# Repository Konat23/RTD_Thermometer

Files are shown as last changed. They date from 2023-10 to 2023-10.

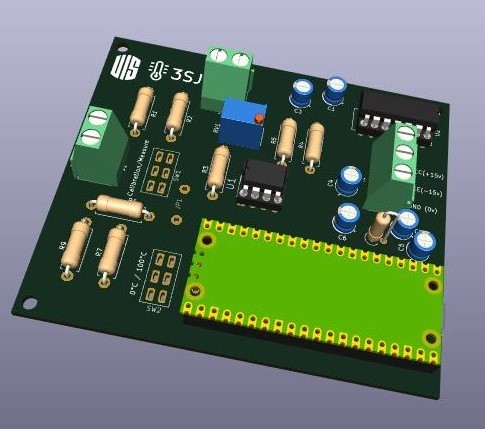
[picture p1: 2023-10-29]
pcb/docs/RTD_3D.jpg

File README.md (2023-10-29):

# RTD_Thermometer
A system that allows to measure and visualize the temperature using a thermal resistance sensor (RTD). The system was designed to measure temperatures between 0°C and 100°C with a precision of 0.1°C

## Team members
- Juan Sebastian Guerrero Peña

- Sebastian Garcia Angarita

- Juliana Lucía Pineda Cardozo 

- Laura Sofía Valero García

## Summary of Results
### Hardware design (PCB assembly)
pcb_final

### Software design (User Interface)
pyplotter

### System in operation results
Pt100_Vs_others

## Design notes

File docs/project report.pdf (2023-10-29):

# SISTEMA DE MEDICION DE TEMPERATURA ´

Guerrero Pena Juan Sebastian ˜
juan2190435@correo.uis.edu.co

García Angarita Sebastian´ sebastian2191472@correo.uis.edu.co

Valero García Laura Sofía laura2180409@correo.uis.edu.co

Pineda Cardozo Juliana Lucía juliana2185105@correo.uis.edu.co

ABSTRACT

In this project, a system that allows to measure and visualize the temperature using a thermal resistance sensor (RTD) will be implemented through different stages; linearization, filtering and digitalization, using analog and digital components in the design of these, considering the recommendations given. The project includes the design and PCB assembly of the system, as well as the visualization of the results in a graphical interface and the evaluation of the signal to noise ratio of the system.

RESUMEN

En este proyecto, se implementara un sistema que permita ´ medir y visualizar la temperatura utilizando un sensor de resistencia termica (RTD) por medio de diferentes etapas; ´
linearizacion, filtrado y digitalizaci ´ | on, utilizando componentes ´
analogicos y digitales en el dise ´ | no de estas, teniendo en cuenta ˜
las recomendaciones dadas. El proyecto incluye el diseno y ˜ ensamblaje en PCB del sistema, así como la visualizacion de ´
los resultados en una interfaz grafica y la evaluaci ´ | on de la ´
relacion se ´ | nal a ruido del sistema. ˜

### 1. INTRODUCCION´

El diseno de un sistema de medici ˜ | on de temperatura con ´
RTD es un proyecto que combina elementos analogicos y ´ digitales para obtener mediciones precisas y confiables de la temperatura utilizando un sensor de resistencia termica (RTD), ´
el cual se basa en la variacion de resistencia el ´ | ectrica en ´
funcion de la temperatura. ´
Este tipo de sensor es utilizado en una amplia gama de industrias como la automotriz, la electronica, la alimentaria ´
y la farmaceutica, debido a su alta precisi ´ | on y estabilidad, ´
ya que en estos campos se requiere un control preciso de la temperatura para garantizar la calidad y seguridad de los productos.
Por medio de este proyecto se puede verificar que a medida que la temperatura aumenta, la resistencia del RTD tambien´ se incrementa de manera predecible y lineal, permitiendo una medicion precisa de la temperatura. ´
Se busca ensamblar el diseno propuesto en este infor- ˜ me en una placa de circuito impreso (PCB) verificando su funcionamiento, al igual que al permitir la posibilidad de ser digitalizados se pueden visualizar los resultados en una
interfaz grafica lo cual facilita la interpretaci ´ | on y el an ´ | alisis ´

de los datos de temperatura, así como su monitoreo en tiempo real.

### 2. OBJETIVO GENERAL

Implementar un sistema de medicion de temperatura con ´ RTD usando elementos analogicos y digitales que permitan ´ visualizar la senal de temperatura. ˜

### 3. OBJETIVOS ESPECÍFICOS

Disenar un sistema de medici ˜ | | on de temperatura teniendo ´
en cuenta las características de la senal proporcionada ˜ por el sensor RTD usado.
Simular el sistema disenado verificando el funcionamien- ˜ to de cada etapa.
Digitalizar la senal de salida del sistema visualizando los ˜ resultados en interfaz grafica en PC. ´
Disenar y ensamblar un circuito Impreso para el sistema ˜ verificando su funcionamiento.
Determinar la relacion se ´ nal a ruido del sistema. ˜

### 4. MARCO TEORICO ´

Para este proyecto se usara como referencia el dise ´ | nõ
propuesto en [1], el cual se resumen en 5 partes; Circuito
de excitacion, circuito de linealizaci ´ | on, filtro pasa bajas, digi- ´
talizacion y cancelaci ´ | on de offset. ´

### 4.1. Circuito de excitacion´

Dado que la temperatura afecta la resistencia de la PT100, se necesita un circuito que permita la conversion de resistencia a ´
una senal el ˜ | ectrica. Para este prop ´ | osito, se emplear ´ | a el puente ´
de Wheatstone, representado en la Figura 1, que posibilita la transformacion de los valores de resistencia en valores de ´ tension. ´
La relacion entre la se ´ | nal de salida respecto a sus variables ˜
esta dada por:

Vout =

RT D
R1 + RT D

−

R3
R3 + R2
Vcc | (1)
Graficando la funcion de la Ecuaci ´ | on (1) en funci ´ | on de la ´
resistencia RT D y para distintos valores de R1 y R2, en la Figura 2 es evidente que la relacion entre la resistencia y la ´ salida no es lineal, sin embargo puede atenuarse este efecto usando valores altos de R1 y R2 y usar un rango de resistencia de la RT D que no se alejen mucho de R3. Para este proyecto se disenõ el sistema para trabajar entre 0 y 100°C, para el ´ caso de la PT100 esto equivale a una resistencia entre 100 y 138.5Ω.

Figura 1: Modelo del Puente de Wheatstone

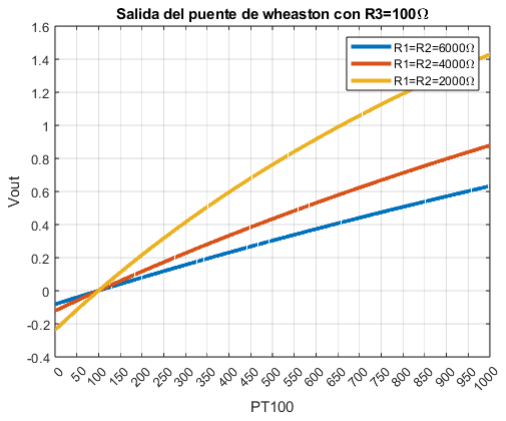
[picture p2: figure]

Figura 2: Salida del Puente de Wheatstone en funcion de la ´ resistencia Rx

### 4.2. Circuito de linealizacion´

Si bien la PT100 es uno de los sensores mas lineales que existen en el mercado, la relacion Temperatura-Resistencia ´ exhibe un comportamiento no lineal de segundo orden como se muestra en la Figura 3, de acuerdo con Bruce-Trump
[2] este problema puede ser compensado considerablemente conectando en cascada a la salida una amplificador con una
pequena retroalimentaci ˜ | on positiva como se muestra en la ´
Figura 4.
La dos parametros a ajustar en este etapa es la resistencia de ´ ganancia R8, y la resistencia de retroalimentacion positiva R5, ´
que no puede ser muy pequena por que se podr ˜ | ía desestabilizar
el circuito. El calculo de estos dos parametros son expresiones ´ largas que dependen de los rangos de salida y de entrada que se quieran medir y son facilitados en [2].

### 4.3. Circuito de filtrado de la senal ˜

Antes de la digitalizacion de la se ´ | nal es necesario hacer ˜
un filtrado a la senal para eliminar el ruido y asegurar el ˜ cumplimiento del teorema de Nyquist. Para esta etapa de filtrado, se emplea un filtro pasa bajas de segundo orden con la conocida topología Sallen-Key. Esta configuracion es ´ ampliamente utilizada en la construccion de filtros activos ´ debido a su relativa simplicidad, versatilidad y rendimiento

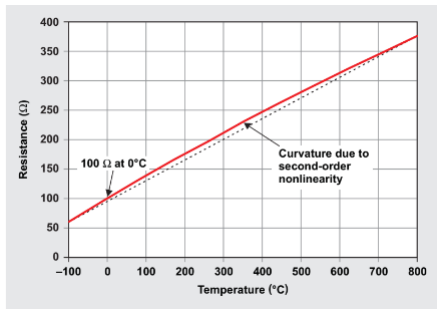
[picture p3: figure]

Figura 3: No linealidad de segundo orden. Fuente: [2]

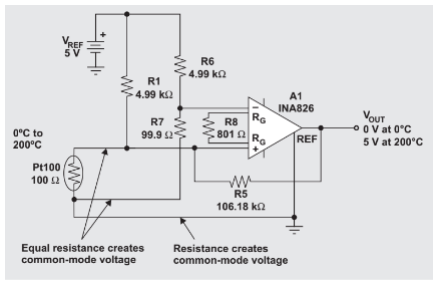
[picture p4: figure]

Figura 4: Retroalimentacion positiva para compensar no linealidad. ´ Fuente: [2]

efectivo. El circuito se configura como un filtro pasabajas o pasaalta de dos polos, donde se emplean dos resistencias, dos capacitores y un amplificador. Si se requiere un orden mayor de filtrado, es posible implementar multiples etapas en ´ cascada.
La topología Sallen-Key permite el paso de frecuencias bajas mientras atenua las frecuencias altas, lo cual es ideal para ´ el diseno de un filtro de segundo orden pasabajas, logrando ˜ así el objetivo de la etapa de filtrado en nuestro sistema de medicion de temperatura. ´

Figura 5: Topología filtro Sallen-Key de segundo orden. Fuente: [3]

En este tipo de circuito, a frecuencias altas los capacitores se comportan como corto circuitos, por lo tanto el terminal positivo del amplificador va a ir a tierra, teniendo una re-
troalimentacion positiva, la salida, tendr ´ | a la misma tensi ´ | on´

que el terminal positivo. A bajas frecuencias, los capacitores
actuaran como circuito abierto, y las dos resistencias estar ´ | an´
en serie, logrando así que a frecuencias bajas, la tension de ´ salida sea igual a la de entrada. Hay que tener en cuenta que el amplificador utilizado en este ejemplo es un buffer o de ganancia unitaria, cuando se quiere variar la ganancia se suele
poner un divisor de tension en el lazo de retroalimentaci ´ | on. ´
La respuesta en frecuencia para un circuito pasa bajas de segundo orden como el de la Figura 5 se muestra en la Figura 6 donde la pendiente de caída es de 40dB/decada.

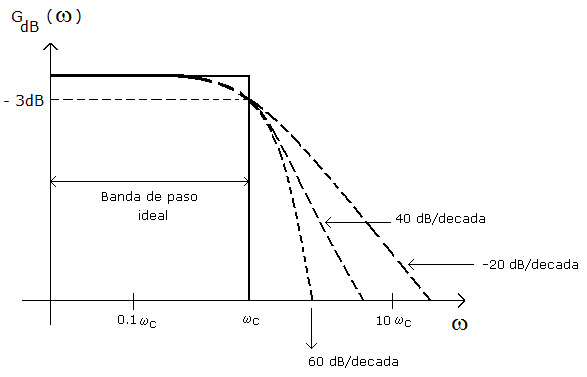
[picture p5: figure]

Figura 6: Respuesta en frecuencia filtro pasa bajas de segundo orden pasabajas. Fuente: [4]

La respuesta en frecuencia de este circuito se da por la expresion: ´
Fc =

1
2π

√
R11R12C11C12

(2)

Los pasos a seguir luego de determinar la frecuencia de corte son los siguientes:
Elegir el valor de un capacitor.
Establecer C1 = 2C2.
Elegir los valores de la resistencia.
El valor del factor de calidad y el de la constante K a la
hora de disenar el circuito, dependen de la aproximaci ˜ | on que ´
se elija.

### 4.4. Circuito de digitalizacion´

Para la digitalizacion de la temperatura medida se hace uso ´ del microcontrolador Raspberry Pi Pico. El primer microcontrolador de la familia Raspberry Pi que usa el microcontrolador RP2040 y ofrece algunas ventajas sobre la familia de microcontroladores Arduino. La placa de desarrollo es de bajo costo,
tamano reducido y bajo consumo energ ˜ | etico. ´
Segun la documentaci ´ | on t ´ | ecnica del microcontrolador [5], ´
Este integra un ADC de 12 bits de resolucion, una frecuencia ´ de muestreo de 500ksps y opera con una tension de referencia ´ interna de 3.3V.
La resolucion se refiere a la cantidad de niveles discretos ´ que el ADC puede representar en su salida digital. Con 12 bits, el ADC es capaz de generar 2

12 = 4096 niveles discretos diferentes.
El rango de voltaje de referencia utilizado en la Raspberry Pi
Pico es de 3.3V. Cuando se realiza la conversion de una se ´ | nal ˜

analogica a un valor digital, el ADC asigna uno de los 4096 ´
niveles logicos para representar el valor de la se ´ | nal anal ˜ | ogica ´
en ese instante.
Para calcular la resolucion del ADC se realiza la siguiente ´ operacion: ´

Resolucion =

3,3V
4096
= 0,00080566V | (3)
El ADC tiene la capacidad de representar una senal anal ˜ | ogi- ´
ca con una precision aproximada de 0.00080566406V por ni- ´ vel digital. Esta característica resulta sumamente util al obtener ´ mediciones precisas, especialmente cuando se digitaliza una
senal pero el rango de tensi ˜ | on es bajo. La alta resoluci ´ | on´
del ADC contribuye significativamente a obtener mediciones confiables y precisas.

### 4.5. Cancelacion de offset ´

El offset en la senal anal ˜ | ogica puede generar errores signifi- ´
cativos en las mediciones, siendo comunmente a ´ | nadido por los ˜
opamps. Para eliminar este offset, se considero inicialmente la ´
opcion de utilizar el DAC MCP47 debido a su alta resoluci ´ | on´
y facilidad de uso. Al tratarse de un DAC de 12 bits, puede
generar hasta 4096 niveles de voltaje, y su senal se usar ˜ | ía para
cancelar el offset inherente a la etapa analogica. ´
Sin embargo, debido a que el offset es una tension constante ´
y muy pequena, utilizar ˜ | unicamente el DAC para generar un ´
nivel constante puede resultar en empeorar la senal debido al ˜ reuido y la precision del DAC. ´
Por esta razon, se opt ´ | o por una cancelaci ´ | on de offset de ´
forma digital, que ofrece facilidad en su implementacion, ´ ademas de la capacidad de realizar ajustes y calibraciones ´
rapidas y confiables para eliminar peque ´ | nos errores. Esta ˜
estrategia permite corregir efectivamente las desviaciones no
deseadas en la senal anal ˜ | ogica, reducir costos y tama ´ | no del ˜
sistema, y asegurar mediciones mas precisas y consistentes. ´

### 5. METODOLOGÍA EXPERIMENTAL

5.1. Circuito de excitacion y linealizaci ´ | on´
La etapa de excitacion y linealizaci ´ | on del sistema se someti ´ | ó
a pruebas exhaustivas a traves de simulaciones y montajes en ´ el laboratorio.
El diseno se evalu ˜ | o mediante simulaciones para asegurar ´
que cumpliera con los requisitos de rendimiento y precision. ´
Posteriormente, se procedio a realizar el montaje f ´ | ísico del
circuito en el laboratorio para verificar su funcionamiento en condiciones reales.
5.1.1. Simulacion circuito de excitaci ´ | on y linealizaci ´ | on´
Las simulaciones se llevaron a cabo utilizando el software de simulacion Tina Ti [6] y el circuito dado en [2], donde se ´ tiene ya un modulo que permite simular el comportamiento de la PT100. Se ajustaron los valores de entrada y de resistencias para un rango de temperatura entre 0°C y 100°C, y de salida de 0 a 3.0V, este rango se selecciono teniendo en cuenta que el rango de entrada analogico de la Raspberry Pi Pico es de 0 ´ a 3.3V. El montaje de simulacion se muestra en la Figura 7. ´

Figura 7: Simulacion etapa de excitaci ´ | on y linealizaci ´ | on. ´

### 5.1.2. Montaje en laboratorio circuito de excitacion y ´

linealizacion´
Se conecto el INA128 de la forma que se muestra en [8] para estudiar que offset intrínseco se tenia del amplificador Operacional.

Figura 8: Montaje para medir offset INA128.

Luego, siguiendo la configuracion descrita en el apartado 4- ´
A, se realizo un montaje en el cual se reemplaz ´ | o el sensor de ´
temperatura PT100 por una resistencia de 100 Ω con tolerancia de 1 %. Se midio el voltaje a la salida. ´
Despues de eso, se incorpor ´ | o un trimmer de 200 ´ | Ω calibrado
con una resistencia de 138.5 Ω en lugar de la resistencia de 100 Ω para permitir la caracterizacion del offset de salida del ´ circuito de linealizacion´
Para caracterizar la curva de entrada salida desde el circuito de excitacion se uso la PT100 ya que es es una resistencia ´ variable, y le rango que nos interesa es de 100 Ω a 138.5 Ω, se uso como entrada un trimmer de 200 Ω, variando el valor de resistencia en la entrada en los rangos de la PT100 (100 -138.5). El montaje experimental se muestra en la Figura 9.

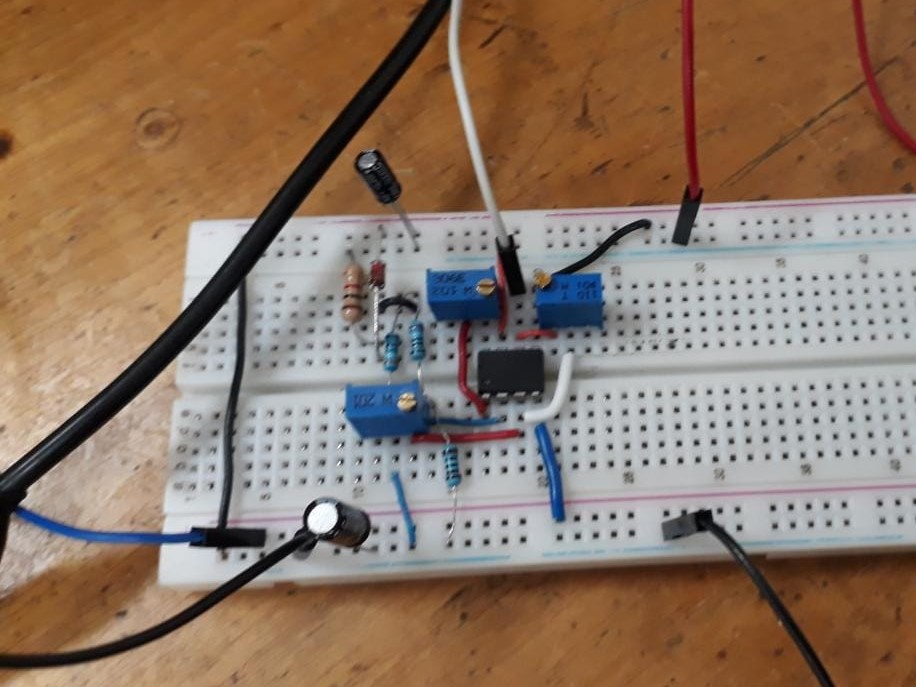
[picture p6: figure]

Figura 9: Montaje en laboratorio etapa de excitacion y linealizaci ´ | on. ´

### 5.2. Circuito de filtrado pasabajas

Usando la topología del filtro sallen-key pasabajas mencio-
nado en el marco teorico y los pasos a seguir para su dise ´ | no, ˜
se implementa un filtro, teniendo en cuenta que tanto varia la temperatura.

### 5.2.1. Diseno del circuito de filtrado pasabajas ˜

La frecuencia de corte utilizada para el diseno de este filtro ˜ debía cumplir con la característica de ser una frecuencia baja con el objetivo de permitir el paso de las frecuencias mas bajas ´ y atenuar las frecuencias altas, por esto mismo, se eligio un ´
valor de 10Hz, aquí se tendra una atenuaci ´ | on de -3dB. ´
En el diseno, al utilizar una aproximaci ˜ | on Butterworth, se ´
esta definiendo un factor de calidad de 0.707, se elige esta ´ aproximacion ya que se quiere obtener una respuesta plana ´ en la banda pasante, esto se refleja en un voltaje de salida constante hasta la frecuencia de corte. Para el calculo de los demas elementos del sistema se tiene en cuenta que el ´ amplificador va a actuar como un buffer, por lo tanto su ganancia va a ser igual a 1.
Calculo del valor de los capacitores: ´
C1 = 10µF => C2 = 2(10µF) | (4)

Calculo del valor de las resistencias: ´

R1 = R2 | (5)

Verificacion en la formula de frecuencia de corte: ´

Fc =

1
2π

p
(1,13kΩ)(1,13kΩ)(10µF)(20µF)

(6)

En resumen, los datos utilizados para la construccion del ´ filtro fueron los siguientes:

Parametro ´ | Valor
Capacitor 1 | 10µF
Capacitor 2 | 20µF
Resistencia 1 | 1,13kΩ
Resistencia 2 | 1,13kΩ
Frecuencia de corte | 10Hz
Q | 0.707
Tabla 1: Descripcion de par ´ | ametros ´
De esta etapa se implemento una simulaci ´ | on y se caracteriz ´ | ó
el circuito en laboratorio.

### 5.2.2. Simulacion circuito de filtrado pasabajas ´

Al circuito que ya se tenia montado en el software de
simulacion Tina Ti, se le agreg ´ | o la etapa de filtrado que se ´
muestra en la Figura 10. Conectando a la entrada senales ˜ de distintas frecuencias y midiendo su salida para hallar la respuesta en frecuencia.

### 5.2.3. Montaje en laboratorio del circuito de filtrado

pasabajas
Se realizo el montaje del filtro pasabajas por independiente ´ para poder estudiar la respuesta en frecuencia haciendo un barrido de frecuencias. El montaje se muestra en la Figura 11.

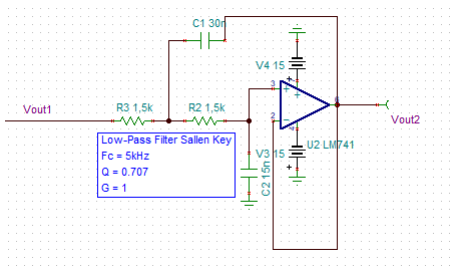
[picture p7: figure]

Figura 10: Simulacion etapa filtrado. ´

Figura 11: Montaje en laboratorio de etapa filtrado.

### 5.3. Caracterizacion PT100 ´

La caracterizacion de la PT100 [7],es una etapa esencial ´ en el desarrollo. Esta fase se lleva a cabo para comprender el comportamiento y la respuesta real de la PT100 ante diferentes condiciones de temperatura, lo que permite calibrar adecuadamente el sistema.
La PT100 es el tipo de RTD mas utilizado en aplicaciones ´ industriales y de medicion de temperatura. Su nombre deriva ´ del estandar que indica que a 0°C debe tener una resistencia ´ de 100Ω. No obstante, cada PT100 puede presentar pequenas ˜ desviaciones o no ser totalmente lineal en su respuesta. Por lo tanto, es esencial caracterizarla y compararla con el estandar ´ de referencia, como se muestra en la Tabla 6.5 en [8], para determinar su comportamiento real y aplicar correcciones a las medidas obtenidas.
Con el fin de realizar la caracterizacion, se llevaron a cabo ´ mediciones utilizando agua a diversas temperaturas, dentro del
rango de 0°C a 100°CPara este prop ˙ | osito, se utilizaron dos ´
sensores de temperatura patron: una termocupla del mult ´ | ímetro
digital UNI-T UT33C+ [9] y un termometro de alimentos ´ TP300 [10].
Los dos sensores, junto con la pt100, fueron cuidadosamente ubicados en un mismo punto y a la misma altura, garantizando mediciones precisas y coherentes entre los dispositivos. Este enfoque nos brindo datos confiables y detallados, esenciales ´ para llevar a cabo la caracterizacion requerida de manera ´ efectiva.

Figura 12: Termocupla del multímetro digital UNI-T UT33C+

Figura 13: Termometro Digital TP300 ´

Figura 14: Montaje en laboratorio de etapa de caracterizacion PT100 ´

### 5.4. Digitalizacion´

En el proceso de digitalizacion, se siguieron algunas reco- ´ mendaciones proporcionadas en el datasheet de la Raspberry Pi Pico sobre el uso del ADC [5, p. 17-19]. Estas recomendaciones incluyen desactivar el modo de ahorro de energía para eliminar el rizado en la alimentacion y garantizar una mayor ´ estabilidad durante las mediciones.
Ademas, se a ´ | nadi ˜ | o una resistencia entre los pines ´
ADC VREF y 3V3 (ver Anexo 1) para reducir el offset en la senal. Sin embargo, es importante mencionar que esta ˜ reduccion del offset incrementa el ruido del ADC. Para contra- ´ rrestar tanto el ruido como el offset, se promediaron multiples ´ muestras y uso un segundo canal del ADC conectado a GND ´ y se considero esta medida como el offset propio del ADC. ´ Sin embargo, durante las pruebas en laboratorio, se observó que la cancelacion de offset empeoraba las mediciones y, ´ contrariamente, introducía un offset negativo en las medidas.
Por esta razon se opt ´ | o por no hacer esta cancelaci ´ | on de ´
offset y mejorar las mediciones usando una calibracion con ´ las resistencias de referencia.

### 5.5. Sistema de auto calibracion´

Para la correccion del offset de las etapas anal ´ | ogicas y ´
el offset del ADC, así como para garantizar un correcto funcionamiento del sistema y mitigar posibles efectos de constantes externas o desajuste en la ganancia, se implementó un sistema de auto calibracion. Este sistema utiliza resistencias ´ de referencia que posibilitan el ajuste preciso de la etapa de digitalizacion. ´

Figura 15: Sistema de auto calibracion´

A traves de un arreglo de switches, Figura 15, es posible ´ alternar entre las resistencias de referencia, lo que permite al microcontrolador ajustar dos puntos de calibracion clave. ´ Gracias a este enfoque, no es necesario calcular o medir el offset en la etapa analogica ni en el ADC. En su lugar, el ´ microcontrolador puede trazar una recta entre esos puntos de
calibracion, calcular su ecuaci ´ | on y, debido a la linealidad del ´
sistema, obtener mediciones precisas y confiables de cualquier resistencia, y por ende, la temperatura de la PT100.

### 5.6. Interfaz de visualizacion´

Para la visualizacion de la temperatura, se desarroll ´ | o una ´
interfaz grafica en Python llamada PyPlotter [11]. Esta interfaz ´ permite establecer conexion con cualquier microcontrolador ´ mediante el protocolo UART y visualizar graficamente los ´ valores enviados por el microcontrolador.

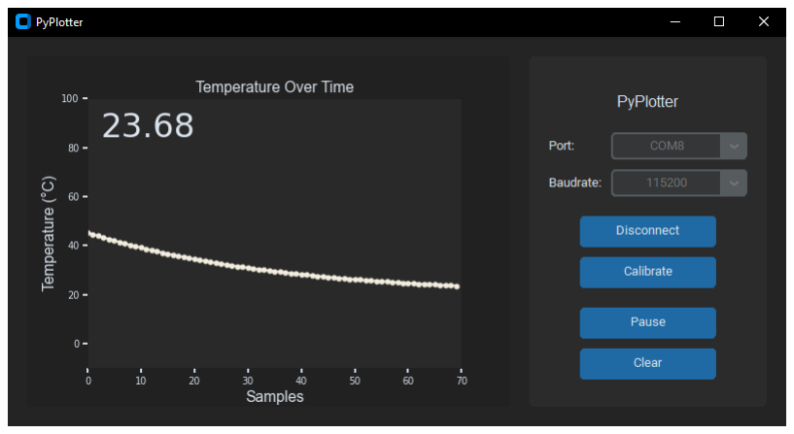
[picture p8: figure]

Figura 16: Interfaz grafica PyPlotter ´

Es importante destacar que la programacion en MicroPython ´ o CircuitPython, utilizadas en la Raspberry Pi Pico, no permite una comunicacion directa mediante el protocolo UART a ´ traves de USB. En su lugar, se emplea el REPL (Read-Eval- ´ Print Loop) que funciona como una terminal interactiva en el microcontrolador, permitiendo enviar comandos y recibir respuestas.
Debido a esta limitacion, la Raspberry Pi Pico fue progra- ´ mada utilizando el IDE de Arduino en lenguaje C++, lo que
permitio establecer la comunicaci ´ | on mediante UART y enviar ´
los datos necesarios para su visualizacion en la interfaz gr ´ | afica ´
PyPlotter.
Ademas, la interfaz proporciona la opci ´ | on de realizar la ´
calibracion del sistema. Esto permite calibrar inicialmente ´ utilizando una resistencia de referencia y luego cambiar a otra resistencia para completar la calibracion de manera efectiva. ´ Aunque PyPlotter se creo originalmente para este proyecto ´ en particular, ha experimentado una evolucion significativa ´ y se ha convertido en un proyecto paralelo utilizado en
otras asignaturas. Su facil personalizaci ´ | on y funcionalidad han ´
sido favorables en distintos contextos, proporcionando una herramienta valiosa para la visualizacion de datos provenientes ´ de microcontroladores.

### 5.7. Diseno de PCB ˜

Luego de verificar el funcionamiento del circuito en el
laboratorio, se procedio al dise ´ | no y montaje de la impresi ˜ | on´
del circuito en una PCB. El montaje incorporo el sistema de ´
switches mencionado en la Seccion de Auto Calibraci ´ | on (ver ´
Seccion´ 5.5).

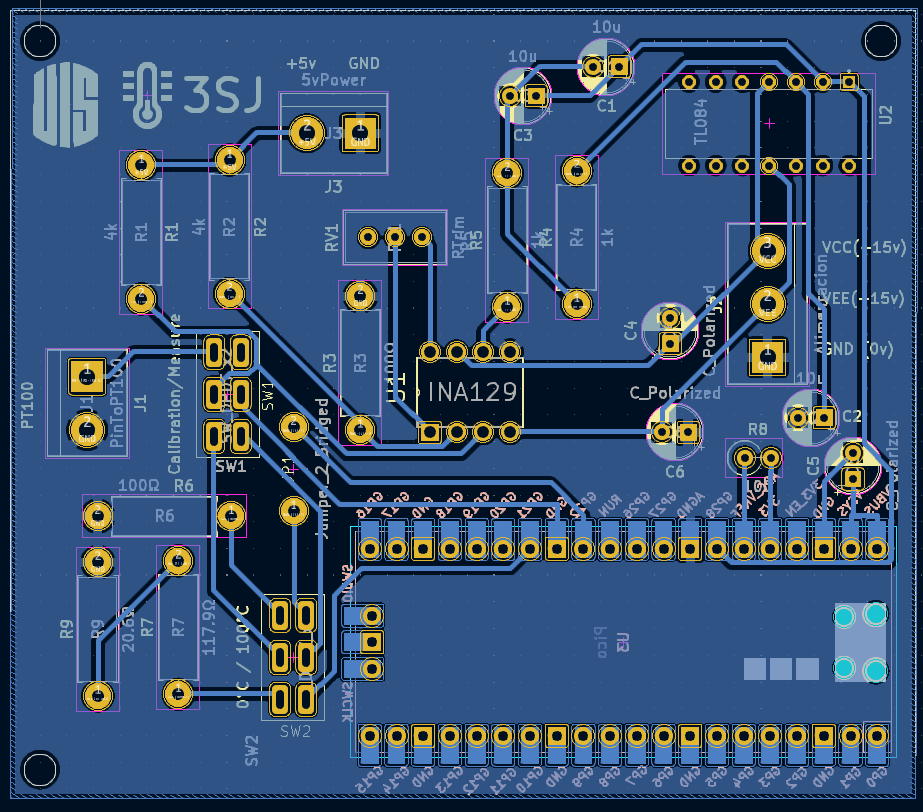
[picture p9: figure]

Figura 17: Diseno de PCB. ˜

El diseno de la PCB se presenta en la Figura 17, mientras ˜ que el esquema de conexiones se muestra en el Anexo 1. El layout de la PCB se proporciona a escala real en el Anexo
2. Asimismo, para una mejor visualizacion y comprensi ´ | on del ´
diseno, el modelo 3D de la PCB se puede ver en la Figura 18. ˜

### 6. ANALISIS DE RESULTADOS ´

6.1. Circuito de excitacion y linealizaci ´ | on´
Se realizo una medici ´ | on experimental del voltaje de offset ´
generado por el amplificador de instrumentacion INA128 ´ utilizando un osciloscopio.


Figura 18: Diseno de PCB visualizado en 3D. ˜

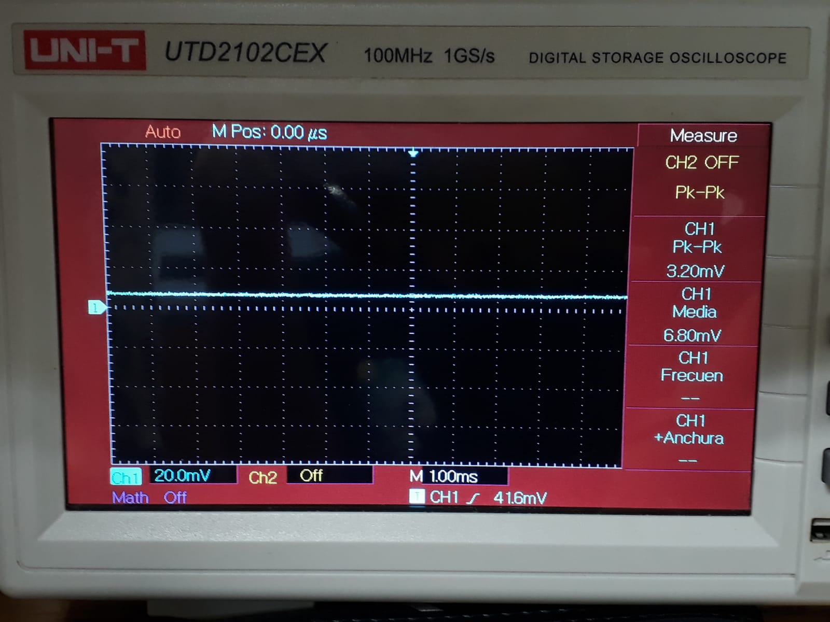
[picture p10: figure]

Figura 19: Offset del amplificador de instrumentacion INA128 ´

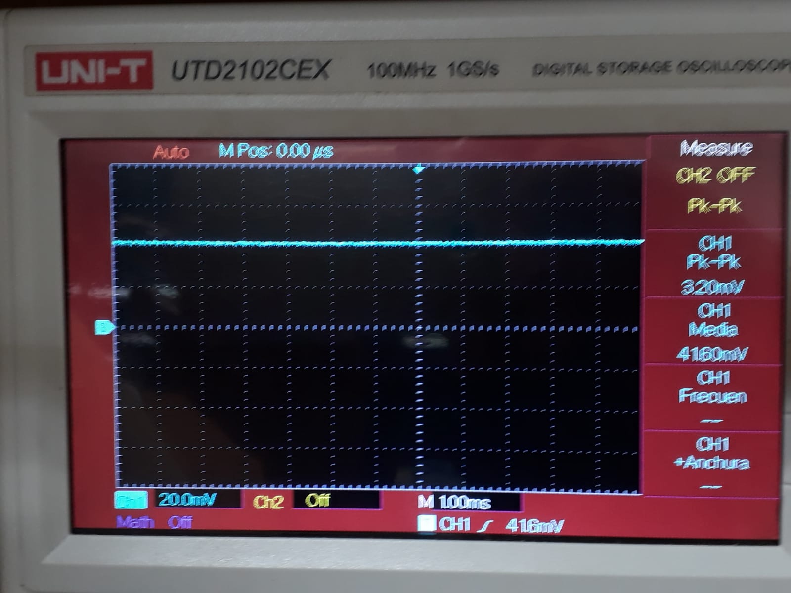
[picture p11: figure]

Figura 20: Offset en 0

◦C

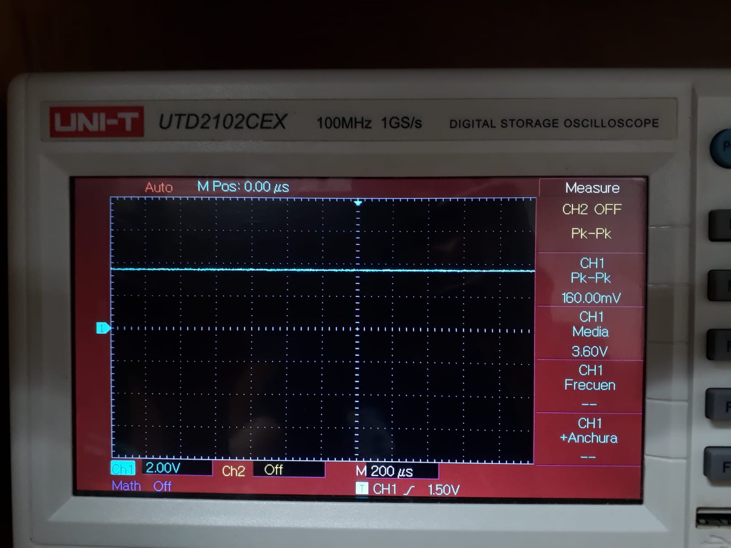
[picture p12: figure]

Figura 21: Offset en 100◦C

6.1.1. Resultados simulacion Circuito de excitaci ´ | on y ´
linealizacion´
Haciendo el barrido en la entrada de 0°C a 100°C, se obtuvo la grafica que se muestra en la Figura 22. ´

Figura 22: Resultado de simulacion barrido de temperatura etapa de ´ linealizacion´

Para el circuito de linealizacion, se realizaron pruebas de ´ comparacion para determinar la necesidad de utilizar feedback ´ positivo dentro del rango de valores de trabajo, que abarcaba desde 0 °C hasta 100 °C. Para ello, se comparo el com- ´ portamiento del circuito con y sin feedback positivo, y los resultados se presentan en la figura 23.
Al analizar los resultados de la comparacion de mediciones ´ y el error, se observo que sin el feedback positivo se obtuvo ´ una menor cantidad de error. Esto se debe a que, teoricamente, ´ como se muestra en la grafica 25, la PT100 dentro de este ´ rango de valores exhibe un comportamiento lineal. Por lo tanto, prescindir del feedback positivo permitio una mayor ´ aproximacion a los valores ideales de la PT100. ´

### 6.2. Circuito de filtrado pasabajas

### 6.2.1. Simulacion circuito de filtrado pasabajas ´

Se hace un barrido en frecuencia para ver como responde el circuito mostrado en la Figura 10, obteniendo la grafica ´ mostrada en la Figura 26.
En la Figura 26, se puede observar el resultado de la simula-
cion del barrido en frecuencia para el filtro pasabajas dise ´ | nado. ˜

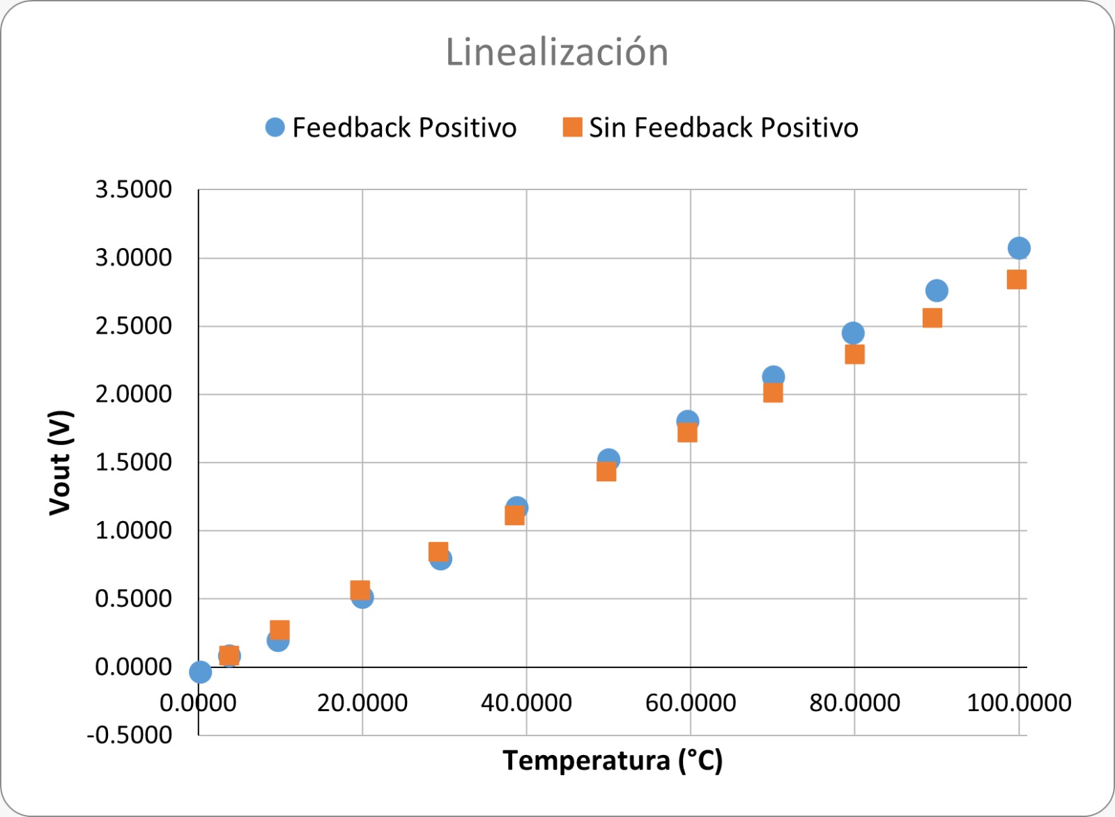
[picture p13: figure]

Figura 23: Comparacion de mediciones con feedback positivo y sin ´ feedback

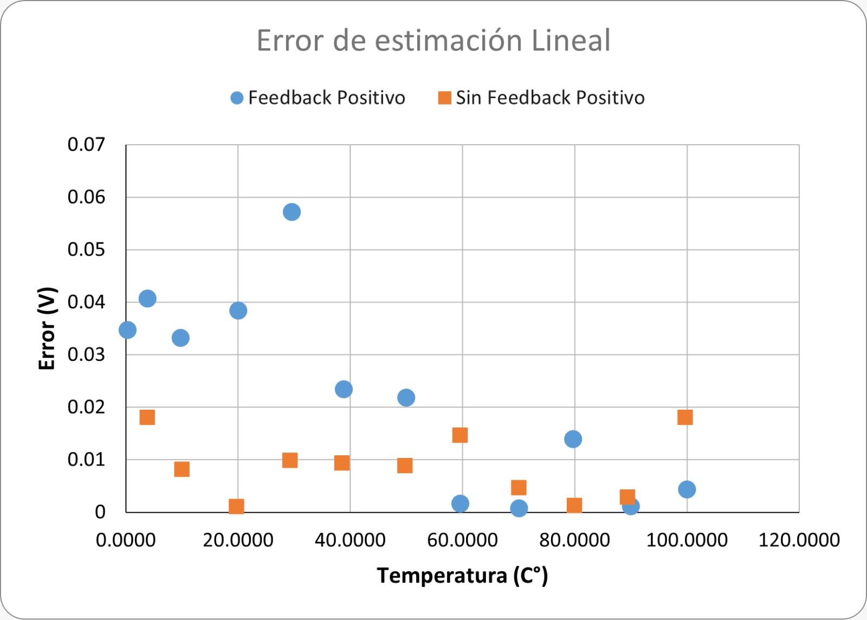
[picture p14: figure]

Figura 24: Error de estimacion lineal ´

Figura 25: Grafica del comportamiento del sensor de temperatura ´ PT-100. Fuente: [12]

Figura 26: Resultado de simulacion barrido en frecuencia para filtro ´ pasabajas

Observamos que la caída de -3dB ocurre en la frecuencia objetivo de 10Hz,con la cual fue disenado el circuito. ˜ Luego, para obtener una validacion experimental del com- ´ portamiento del filtro pasabajas, se realizaron mediciones utilizando dos amplificadores operacionales diferentes. La Figura 27 muestra el resultado experimental del barrido en frecuencia utilizando el amplificador operacional LM741, mientras que la Figura 28 presenta los resultados utilizando el amplificador operacional TL084.

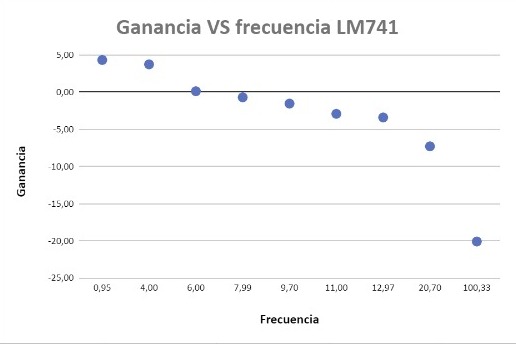
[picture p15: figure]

Figura 27: Resultado experimental de barrido en frecuencia para filtro pasabajas con amplificador LM741

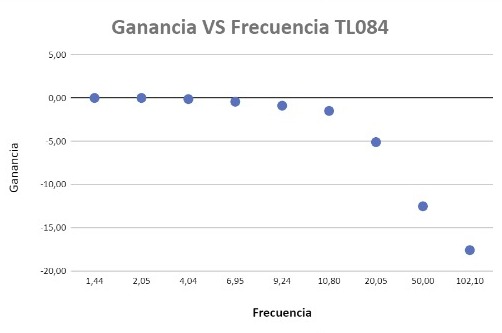
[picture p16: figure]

Figura 28: Resultado experimental de barrido en frecuencia para filtro pasabajas con TL084

En el caso del amplificador operacional LM741, se observa que la caída de -3dB ocurre nuevamente cerca de la frecuencia objetivo de 10Hz. Sin embargo, a medida que aumenta la frecuencia, la atenuacion no se mantiene constante y presenta ´ ciertas fluctuaciones en el comportamiento del filtro. Esto puede deberse a limitaciones del amplificador en altas frecuencias o a efectos de ruido y distorsion que influyen en la respuesta ´ del filtro. Por otro lado, al utilizar el amplificador operacional TL084, se observa un comportamiento mas cercano al de ´ un filtro con una característica tipo Butterworth. La curva
de atenuacion muestra una forma m ´ | as suave y consistente ´
a lo largo del rango de frecuencias medidas. Esto sugiere que el TL084 es mas adecuado para funcionar como un filtro ´

pasabajas con un comportamiento mas predecible y estable en ´ un rango mas amplio de frecuencias. ´

### 6.3. Analisis de ruido ´

En el analisis de ruido del sistema, se llevaron a cabo ´
calculos te ´ | oricos y simulaciones espec ´ | íficas para evaluar el
nivel de ruido presente en el sistema completo, centrandonos ´ principalmente en el ruido de los amplificadores. Los calcu- ´ los teoricos arrojaron un valor estimado de ruido total de ´ aproximadamente 2.3584 µV (Ver anexo 3), mientras que las simulaciones mostraron un valor ligeramente mayor, alrededor de 2.37 µV .

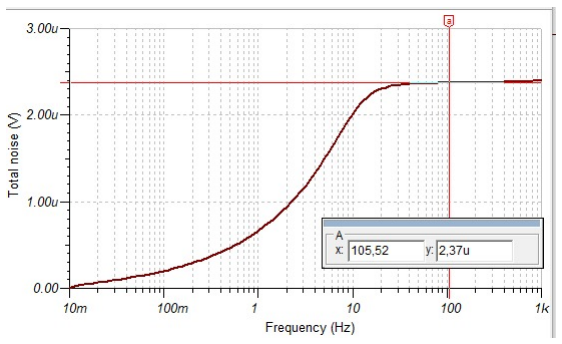
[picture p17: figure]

Figura 29: Resultado analisis del ruido total ´

La Figura 29 presenta los resultados del analisis del ruido ´ total.
Ademas, se realiz ´ | o un an ´ | alisis de la Relaci ´ | on Se ´ | nal-Ruido ˜
(SNR) para evaluar la calidad de la senal de inter ˜ | es en relaci ´ | on´
con el ruido presente en el sistema. La Figura 30 muestra los resultados del analisis SNR, donde se visualiza claramente la ´ relacion entre la frecuencia y la SNR expresada en decibelios ´
(dB).De manera teorica se llego a un ´ | SNR = 65,816dB (Ver
anexo 3) para el ancho de banda de 10Hz, sin embargo no es posible compararlos con los resultados de simulacion ya que Tina-Ti no permite ver el SNR en un ancho de banda definido.

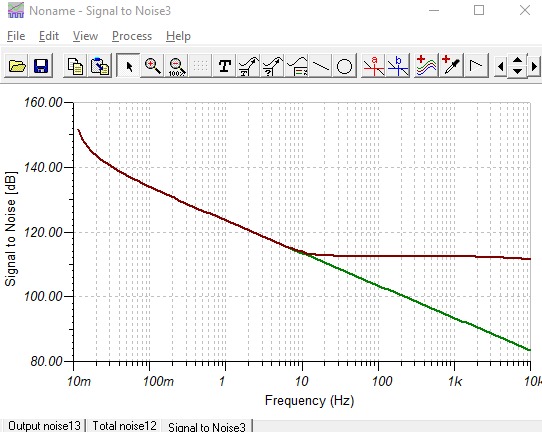
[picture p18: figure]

Figura 30: Resultado analisis SNR ´

Todos calculos te ´ | oricos detallados se encuentran disponibles ´
en el anexo 3 del informe para una referencia detallada. Los
anexos proporcionan una vision completa de la metodolog ´ | ía
utilizada en los calculos te ´ | oricos y permiten una mayor com- ´
prension del an ´ | alisis tanto del ruido como del SNR del sistema. ´

### 6.4. Caracterizacion PT100 ´

Se recolectaron los datos de los dos sensores patron y la ´ PT100, tal como se muestra en la Tabla 2. Luego de obtener
estos datos, se procedio a crear una gr ´ | afica comparativa entre ´
los valores medidos como se ilustra en la figura 31.
PT100 Ω | TP300 °C | Termocupla °C
133.7 | 79.3 | 81
130.9 | 74.3 | 72
129.9 | 66.6 | 70
129.1 | 66.5 | 68
127.6 | 63.6 | 64
126.4 | 60.6 | 60
124.8 | 56.3 | 56
122.2 | 50.1 | 49
120.8 | 46.2 | 45
119.3 | 42.5 | 42
117.3 | 37.5 | 37
115.8 | 33.2 | 32
112.9 | 25.4 | 24
110.4 | 20.6 | 17
109.2 | 13.8 | 14
104.7 | 2.1 | 0

Tabla 2: Mediciones de PT100, TP300 y termocupla

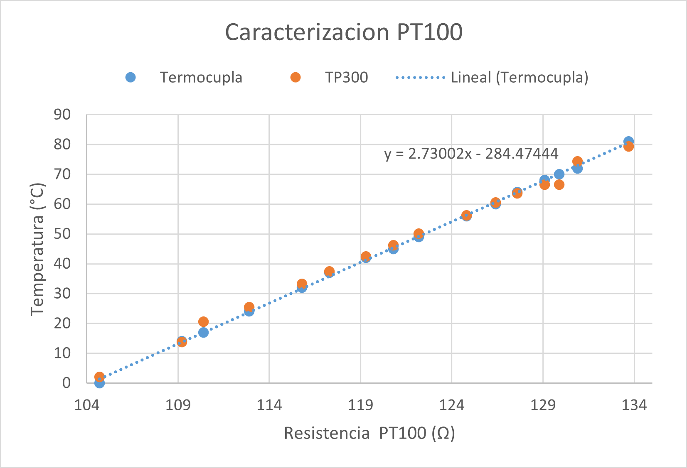
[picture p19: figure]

Figura 31: Curva de caracterizacion PT100 ´

Tras analizar los resultados obtenidos en la Figura 31, se puede concluir que la termocupla presenta un comportamiento
mas lineal en comparaci ´ | on con el sensor TP300. Este aspecto ´
ha sido determinante en la eleccion del sensor patr ´ | on para el ´
proceso de caracterizacion. ´
La termocupla demostro una mayor proximidad y ajuste a ´ la línea recta que representa la variacion de la PT100 respecto ´ a la temperatura. Esta mayor linealidad en el comportamiento de la termocupla sugiere una respuesta mas precisa y confiable ´ a los cambios de temperatura. Como resultado, al utilizar la interfaz para visualizar la temperatura de la PT100, obtuvimos resultados mucho mas cercanos a los proporcionados por la ´ termocupla.

### 6.5. Digitalizacion´

Las pruebas realizadas para la cancelacion del offset propio ´ del ADC demostraron que, contrariamente a lo que se pensaba y recomendaba en el datasheet [5, p. 17], la cancelacion del ´ offset empeoraba las mediciones de voltaje en el ADC. Esto se puede apreciar claramente en la Figura 32, donde se observa
que al medir la maxima tensi ´ | on despu ´ | es de la cancelaci ´ | on del ´
offset, los resultados son peores en comparacion con la lectura ´ directa del ADC.

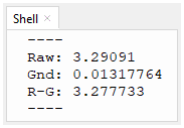
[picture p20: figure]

Figura 32: Resultados de cancelacion offset del ADC ´

Se llevaron a cabo diversas pruebas utilizando distintos voltajes, pero los mejores resultados, comparando con un multímetro y osciloscopio, se obtuvieron al realizar la lectura directa del ADC, sin aplicar la cancelacion de offset. ´
La resolucion del ADC y, por ende, la resoluci ´ | on efectiva ´
en la medicion de la temperatura se ven afectadas por las ´ modificaciones realizadas de acuerdo a las recomendaciones en el datasheet, ver Seccion´ 5.4. Sin embargo, es importante tener en cuenta que el numero efectivo de bits (ENOB) del ´ ADC no es realmente 12 bits, como se menciona en el datasheet de la placa de desarrollo de la Raspberry Pi Pico [5].
En la documentacion del microcontrolador RP2040 [13, ´ sec 4.9.3], se especifica que el ENOB típico es de 8.7 bits. Considerando los ajustes realizados en nuestro sistema y que
la caracterizacion en la documentaci ´ | on se llev ´ | o a cabo con ´
equipos de alta calidad y bajo nivel de ruido, el ENOB de nuestro sistema se estima en aproximadamente 7.96 bits. Este valor se calculo teniendo en cuenta el voltaje registrado con ´ el ADC conectado a GND.

### 6.6. Resultados diseno de la PCB ˜

Una vez impresa la PCB, se procedio al montaje y soldadura ´ de los componentes. Durante esta fase, se llevo a cabo una ´ cuidadosa medicion de las resistencias empleadas, utilizando ´
equipos de medicion de alta precisi ´ | on, con el objetivo de ´
conocer los valores reales del sistema. Esto permitio realizar ´ una calibracion precisa del sistema y ajustar adecuadamente ´ los puntos de referencia del puente de Wheatstone, necesarios para una medicion exacta de la temperatura. ´
En la Tabla 3 se presentan las mediciones de las resistencias utilizadas en la PCB, junto con sus indicativos correspondientes en el esquematico que se encuentra en el Anexo 1. ´

### 6.7. Resultado final

Despues del montaje en PCB del sistema se hicieron pruebas ´ finales del comportamiento y precision del sistema usando la ´

Resistencia | Valor Ω
R1 | 3880
R2 | 3880
R3 | 99.9
R6 | 100.7
R7 | 117.5
R9 | 20.2

Tabla 3: Valor real de resistencias usadas

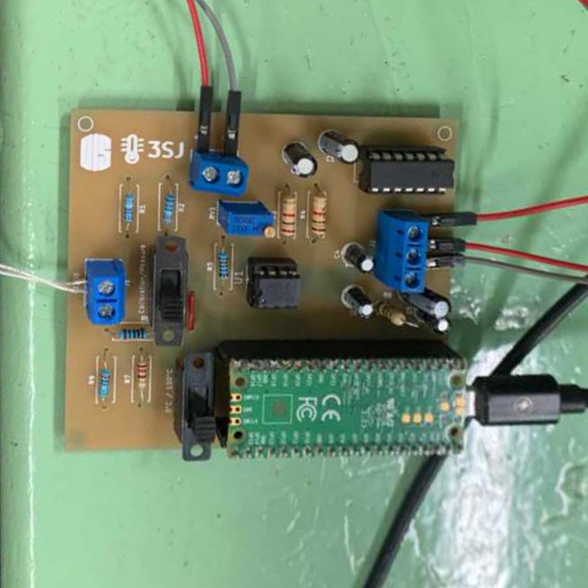
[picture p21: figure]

Figura 33: Resultado final en la PCB

interfaz grafica. En la Figura 34 se muestra un gr ´ | afico com- ´
parativo de temperatura vs. temperatura, donde se comparan las mediciones de la PT100 en la interfaz implementada, con las mediciones realizadas utilizando dos termometros patrones: ´ una termocupla y un TP300.

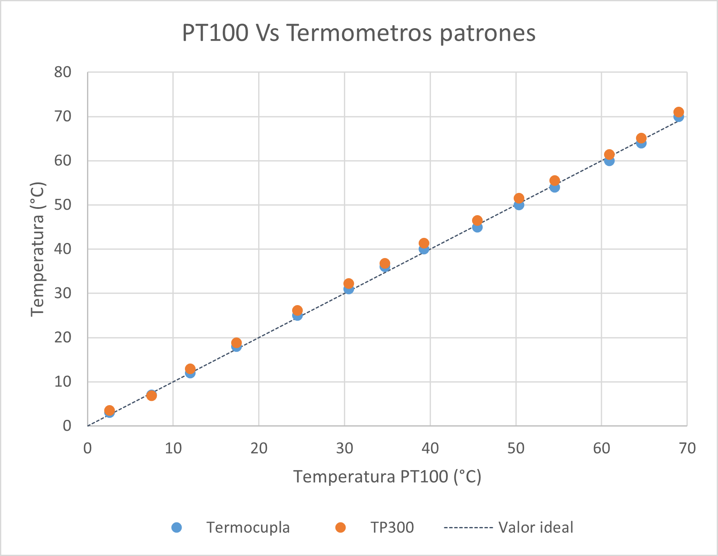
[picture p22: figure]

Figura 34: Comparacion de mediciones de temperatura utilizando ´ PT100 vs termocupla y TP300

Esta grafica refleja c ´ | omo el medidor de temperatura se ´
desempena en relaci ˜ | on con los term ´ | ometros que fueron selec- ´
cionados previamente. Durante la caracterizacion, se someti ´ | ó
el instrumento a diversas condiciones y rangos de temperatura para evaluar su rendimiento y precision. ´

### 7. CONCLUSIONES

Si bien existe una tabla característica que muestra la relacion entre la temperatura y la resistencia en una ´ PT100, es de vital importancia llevar a cabo una carac-
terizacion espec ´ | ífica de la PT100 que se vaya a utilizar
en el sistema de medicion de temperatura. Esto se debe ´ a que el comportamiento real de la PT100 puede variar significativamente de lo esperado, afectando la precision´ y confiabilidad de las mediciones.
El ADC de la Raspberry Pi Pico, a pesar de no alcanzar los 12 bits de resolucion como lo vende el fabricante, ´ demostro ser suficiente para obtener mediciones de tem- ´ peratura con una precision de hasta 1°C. ´
En conclusion, este proyecto nos ha brindado una valiosa ´ oportunidad para aplicar los conocimientos adquiridos
en la asignatura de diseno de sistemas electr ˜ | onicos. A ´
traves de este proceso, hemos podido profundizar en ´ diversas habilidades, como la investigacion, el trabajo en ´
laboratorio, el diseno de PCB, la instrumentaci ˜ | on y la ´
programacion de microcontroladores. ´
Esta experiencia integral en el campo de la electronica y ´ la ingeniería nos ha fortalecido en terminos de habilida- ´ des tecnicas y blandas, como el trabajo en equipo y la ´ capacidad de resolver problemas complejos. A lo largo del proyecto, hemos enfrentado desafíos y aprendido a superar obstaculos, lo que nos ha proporcionado una base ´ solida para futuros proyectos y aplicaciones en el campo ´ de la electronica. ´
Estamos satisfechos con los resultados obtenidos y creemos que este proyecto ha sido un paso importante para
nuestra formacion acad ´ | emica y profesional. Ha sido una ´
experiencia enriquecedora que nos motiva a seguir explorando y perfeccionando nuestras habilidades en el ambito ´ de la ingeniería electronica, con el objetivo de contribuir ´ al desarrollo de soluciones innovadoras y funcionales en el futuro.

RECOMENDACIONES

Una mejora potencial para futuras versiones de este sistema sería considerar el uso de una resistencia variable en el puente de Wheatstone. Esto permitiría ajustar la resistencia para que el puente este equilibrado a una ´ temperatura específica, como 0°C, lo que eliminaría el
offset en la tension medida y garantizar ´ | ía que la salida
del puente sea 0V a dicha temperatura de referencia.
Para una mayor precision se recomendar ´ | ía usar un ADC
externo que ofrezca una resolucion superior y un ENOB ´ mayor al de la Raspberry Pi Pico. Ademas, se recomen- ´ daría utilizar una fuente de referencia precisa para el ADC. De esta manera, se lograría una mayor resolucion´ en la lectura de la temperatura y se abriría la posibilidad de ajustar el sistema para ampliar a un rango de medicion´ de temperatura mayor a 0-100°C.

Una mejora interesante sería adaptar el sistema para poder conectar una PT100 de 3 hilos. Esta modificacion´ podría aumentar la precision y exactitud de las medicio- ´ nes, ya que permite reducir el efecto de la resistencia del cableado en las mediciones de temperatura.
Utilizar otro microcontrolador de tamano reducido y ˜ con conectividad a internet podría permitir una imple-
mentacion IoT que facilite la instalaci ´ | on, el uso y la ´
visualizacion de los datos, adem ´ | as de reducir los costos ´
de fabricacion. Esta mejora potencial elevar ´ | ía la calidad
del sistema y ofrecería una solucion m ´ | as avanzada y ´
versatil. ´

REFERENCIAS

[1] C. Murphy, “Efficient implementation of analog signal processing functions in xilinx all programmable devices,” Xilinx, Inc, 3 2018.
[2] B. Trump, “Analog linearization of resistance temperature detectors,” Analog Applications, 2011.
[3] “Filtro lineal - academia lab,” Sitio web. [Online]. Available: https://academia-lab.com/enciclopedia/filtro-lineal/
[4] “Filtro | pasa | bajas | butterworth.” | [Online]. | Available:
https://gc.scalahed.com/recursos/files/r145r/w868w/U3liga3.html
[5] R. P. Foundation, “Raspberry pi pico datasheet,” Online, 2023. [Online]. Available: https://datasheets.raspberrypi.com/pico/pico-datasheet.pdf
[6] Texas Instruments, “Tina-ti, texas instruments.” [Online]. Available: https://www.ti.com/tool/TINA-TI
[7] L. S. Cryotronics, “PT100 Datasheet,” Online. [Online]. Available: http://irtfweb.ifa.hawaii.edu/ iqup/domeenv/PDF/pt100plat.pdf
[8] A. Creus, Instrumentacion Industrial ´ | , 8th ed. Alfaomega, 2011.
[9] UNI-T, | UT33C+ | Multimeter | User | Manual, | UNI-T | Group
Corporation, China, 2023, online. [Online]. Available: https://meters.unitrend.com/product/ut33plus-series/
[10] AikTryee, | “PT300 | Manual | de | usuario,” | Onli-
ne, | 2018. | [Online]. | Available: | https://manuals.plus/wp-
content/uploads/2023/06/D1YU5KXb98L.pdf
[11] Sebastian-GA, | “PyPlotter,” | Online, | 2023. | [Online]. | Available:
https://github.com/Sebastian-GA/PyPlotter
[12] A. . C. . Instrumentation, “Nota tecnica PT100,” Online, 2018. [Online]. Available: http://www.arian.cl/downloads/nt-004.pdf
[13] R. P. Foundation, “Rp2040 datasheet,” Online, 2023. [Online]. Available: https://datasheets.raspberrypi.com/rp2040/rp2040-datasheet.pdf

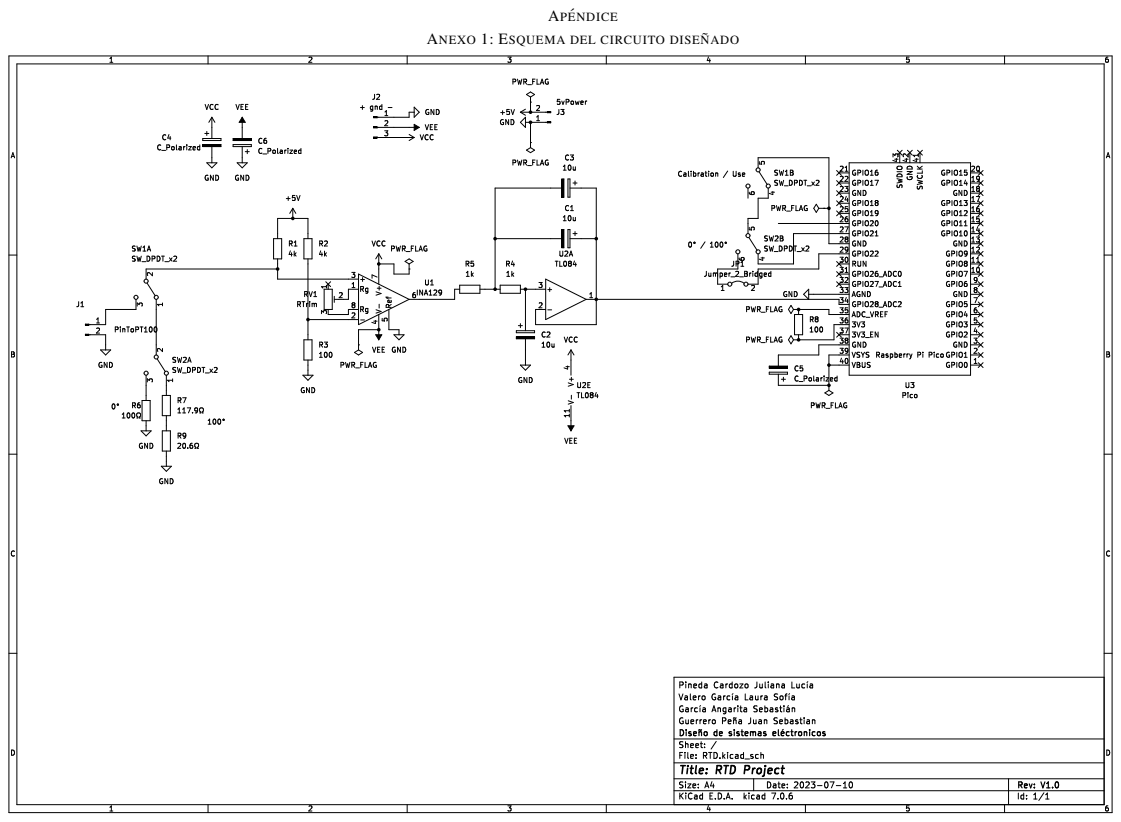
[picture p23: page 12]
APENDICE ´

ANEXO 1: ESQUEMA DEL CIRCUITO DISENADO ˜

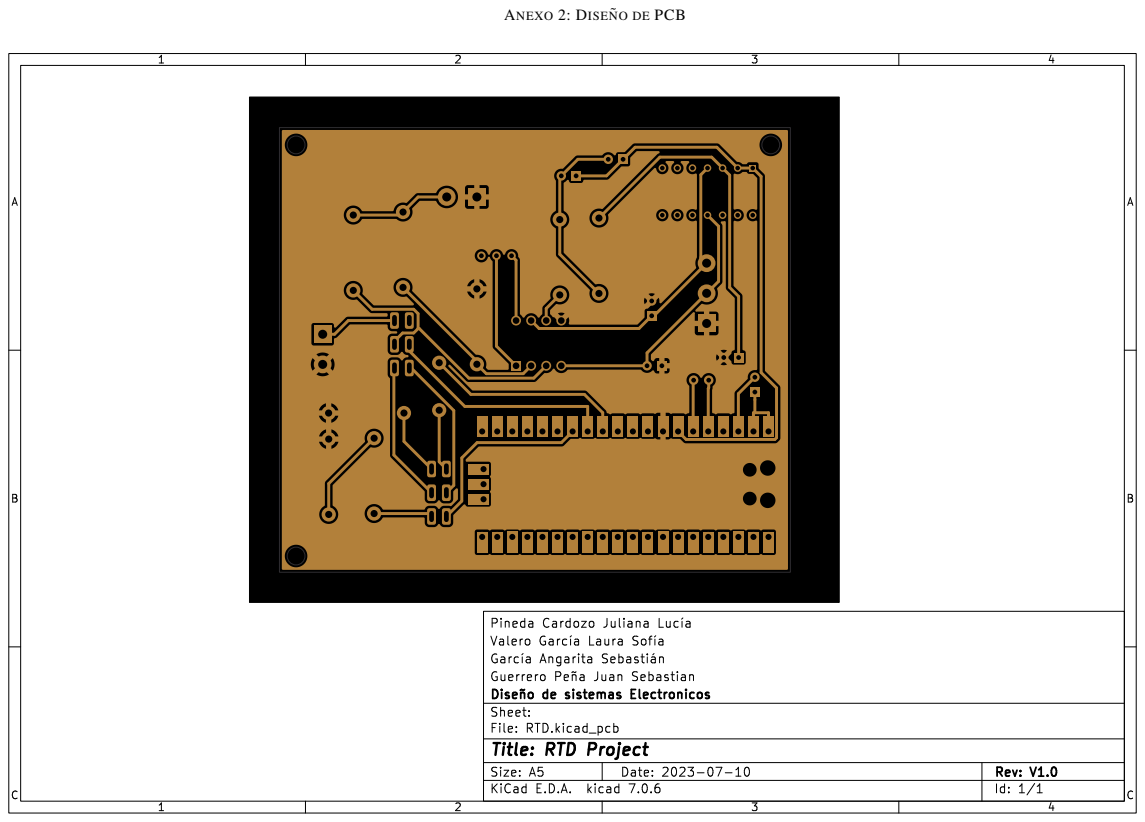
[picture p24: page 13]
ANEXO 2: DISENO DE ˜; PCB

# Calculos de Ruido

En este documento se usaron las siguientes ecuaciones para calcular ruido de banda plana y ruido fliker.

## Ruido de banda plana

### Where:

: Ancho de banda del ruido (Brick Wall filter).

### : Factor de correcion Brick Wall

### : -3dB despues de la frecuencia de corte

### : RMS del tuido total de banda plana

### : Densidad espectarl de la banda plana

## Ruido Flicker

### Where:

### : Densidad de ruido espectral normalizado a un 1 Hz

### : Rudio en la freucencia mas baja dada en la curva 1/f

### : Frecuencia mas baja dada en la curva 1/f

### : Ruido total 1/f en RMS

1

ANEXO 3: CALCULOS DE ´ | RUIDO Y SNR

### : Frecuencia de corte baja

### : Frecuencia de corte alta

## Superposicion de ruidos:

### fuente: https://www.ti.com/video/series/ti-precision-labs-op-amps.html

# Calculos

### Frecuencia de corte

## fc = 11.23; % -3dB despues de los 10hZ Kn = 1.22; % factor usado para filtros de segundo orden

BW = Kn*fc;

## fl = 0.1; % Usado generalmente Gina = 60; %Ganancia del ina Gtl = 1; % Ganancia del TL084

### Ruido en el INA

## % Datos sacados del datasheet

2

## e_BB = 8*10^-9; % nV f0 = 1; %Hz enf =11*10^-9; %nV/raiz(hz)

## % Banda plana Ennb1 = e_BB*sqrt(BW)

Ennb1 = 2.9611e-08

## % Flicker

Enormal = enf * sqrt(f0);

## Enflick1 = Enormal * sqrt(log(BW/fl))

Enflick1 = 2.4399e-08

## % Flicker + pandablana E1 = sqrt(Enflick1^2+Ennb1^2)

E1 = 3.8369e-08

### Ruido del TL

## e_BB = 18*10^-9; % nV

## f0 = 10; %Hz enf =45*10^-9; %nV/raiz(hz)

## %Banda plana Ennb2 = e_BB*sqrt(BW)

Ennb2 = 6.6626e-08

## %Flicker

Enormal = enf * sqrt(f0);

## Enflick2 = Enormal * sqrt(log(BW/fl))

Enflick2 = 3.1564e-07

3

## % Flicker + pandablana E2 = sqrt(Ennb2^2+Enflick2^2)

E2 = 3.2260e-07

### Ruido de resistencias:

k = 1.38*10^-23;
T = 298;

## R = 195.12; % resistencias equivalentes del puente de wheastone ER = sqrt(4*k*T*BW*R)

ER = 6.6313e-09

### Sumar los ruidos:

## Et = sqrt((E1*Gina)^2+(Gina*ER)^2+E2^2)*Gtl

Et = 2.3584e-06

### Ruido total:

# Calculo de SNR

## Psignal = 3^2 % Potencia de la señal DC maxima a la salida

Psignal = 9

## Pnoise = Et % Potencia del ruido total a la salida

Pnoise = 2.3584e-06

## SNR = Psignal/Pnoise

SNR = 3.8161e+06

## SNR_db= 10*log10(SNR) % dB

SNR_db = 65.8162

### SNR en decibelios:

4

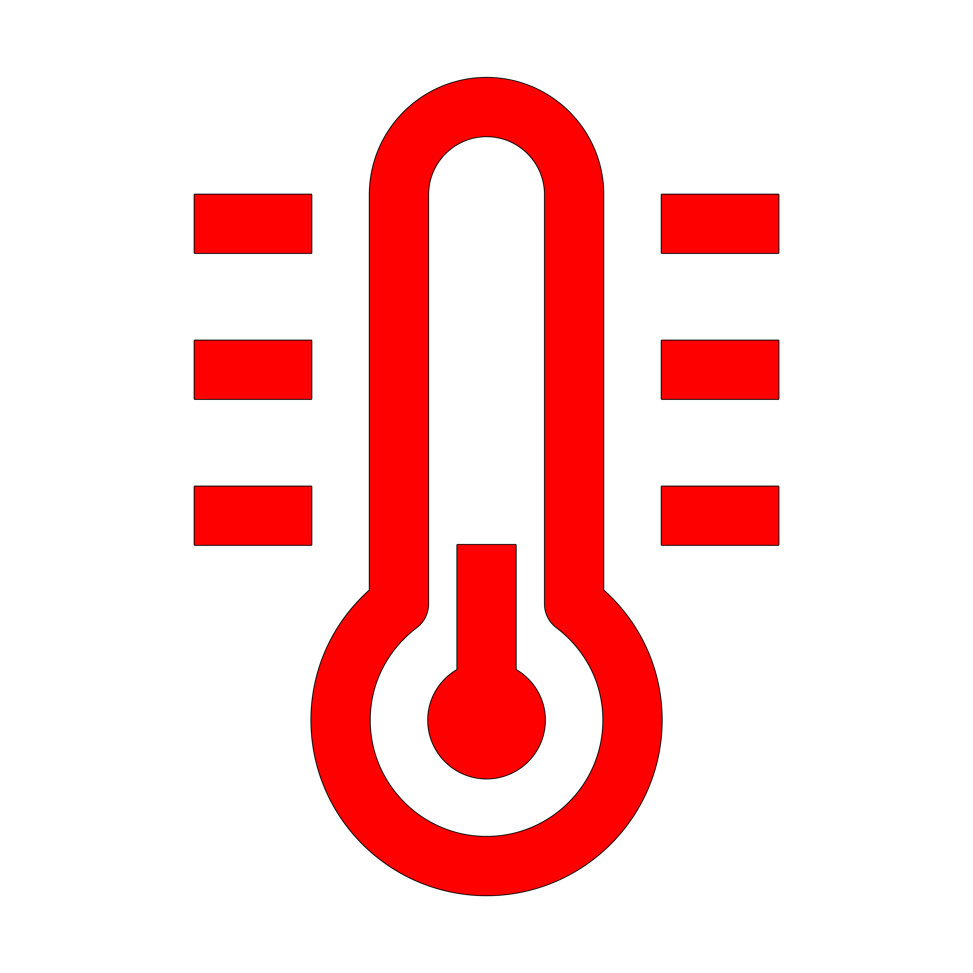
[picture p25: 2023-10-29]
pcb/images/Temperature.png

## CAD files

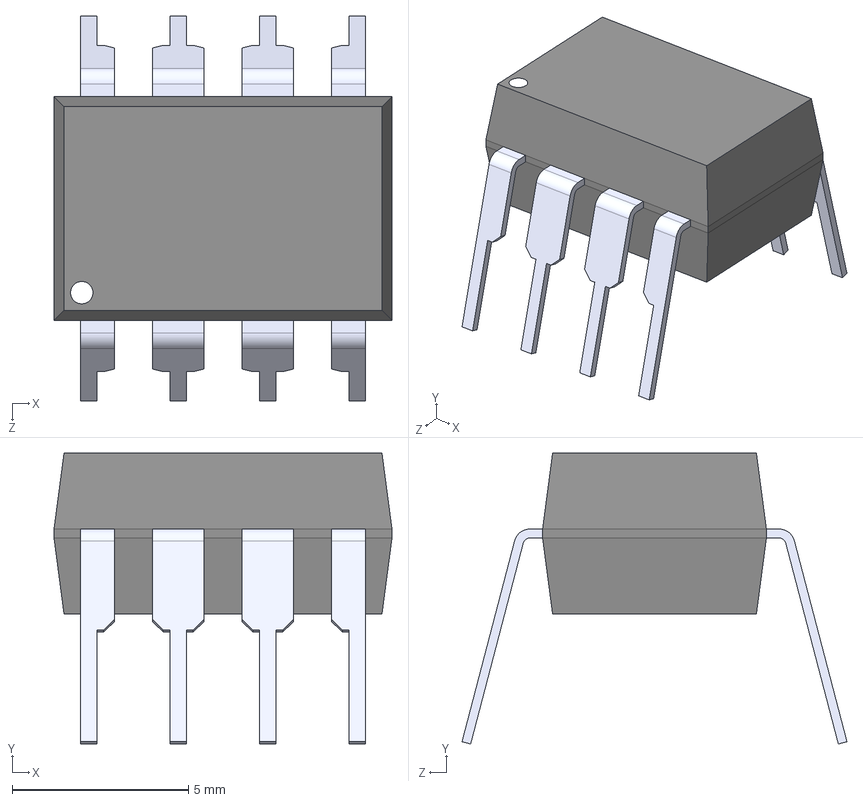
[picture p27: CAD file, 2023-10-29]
pcb/footprints/INA128P/INA128P.step
9.59 x 8.25 x 10.9 mm

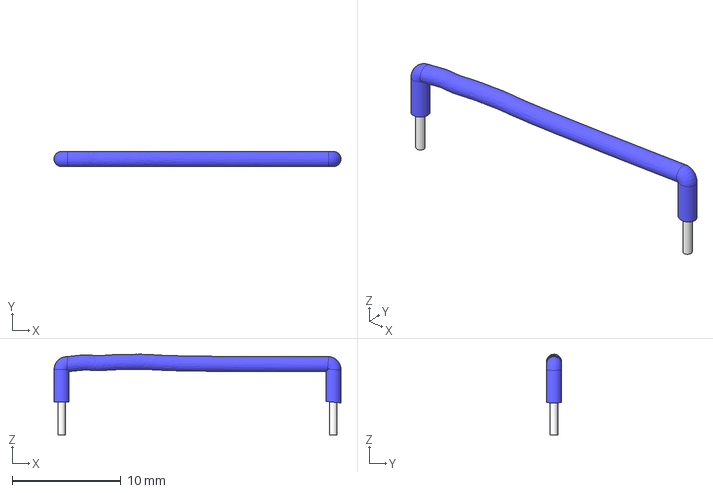
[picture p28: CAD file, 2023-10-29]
pcb/footprints/JumperWires/Jumper-Wire_25mm_Blue.step
26.4 x 1.40 x 7.41 mm

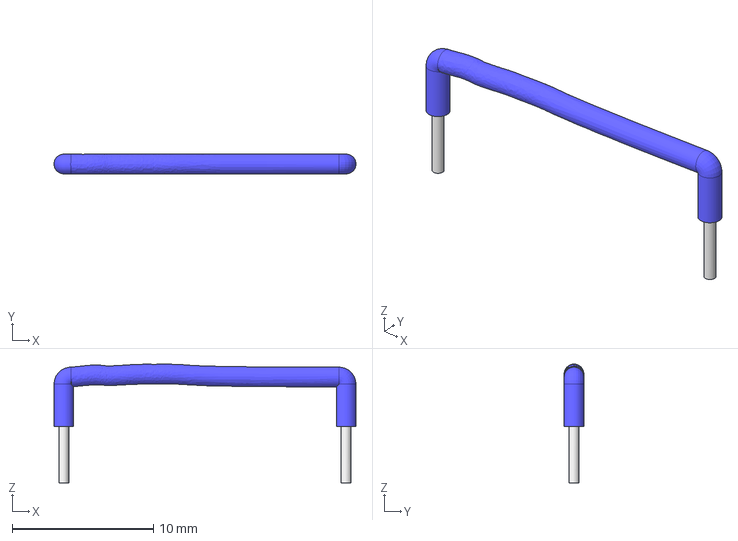
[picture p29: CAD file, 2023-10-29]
pcb/footprints/JumperWires/Jumper-Wire_20mm_Blue.step
21.4 x 1.40 x 8.41 mm

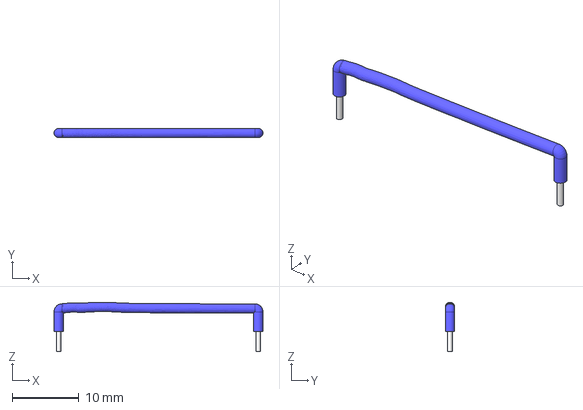
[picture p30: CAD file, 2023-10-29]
pcb/footprints/JumperWires/Jumper-Wire_30mm_Blue.step
31.4 x 1.40 x 7.42 mm

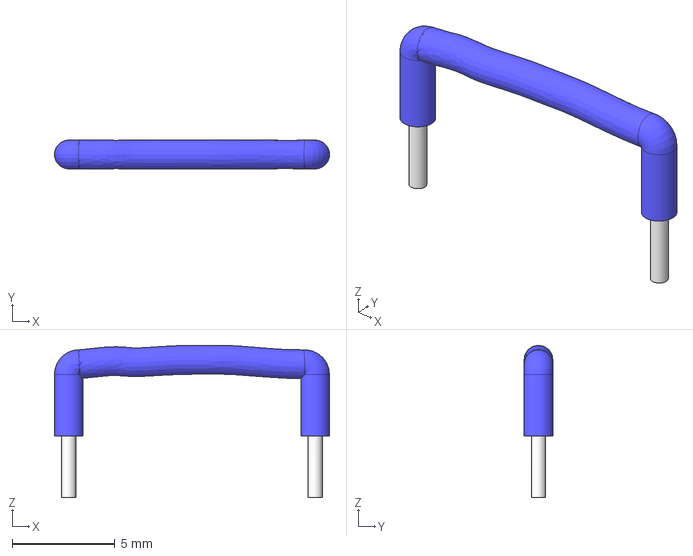
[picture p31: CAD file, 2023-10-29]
pcb/footprints/JumperWires/Jumper-Wire_12mm_Blue.step
13.4 x 1.40 x 7.42 mm

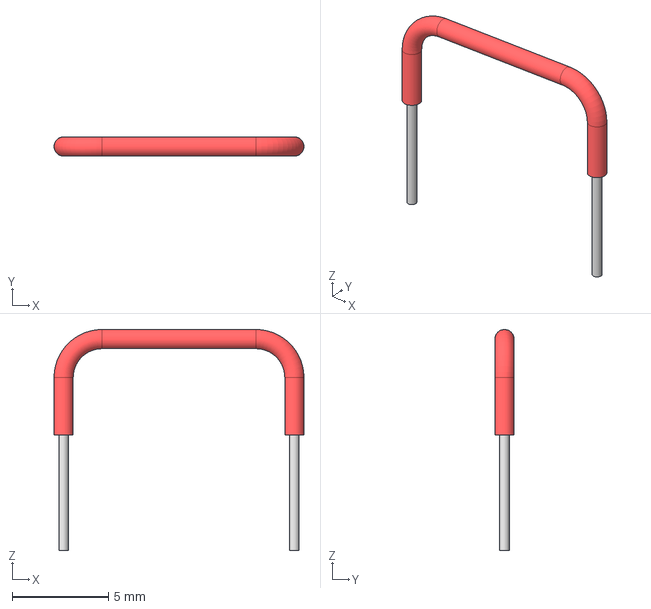
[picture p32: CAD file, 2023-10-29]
pcb/footprints/JumperWires/Jumper-Wire_12mm_Red.step
13.0 x 1 x 11.5 mm

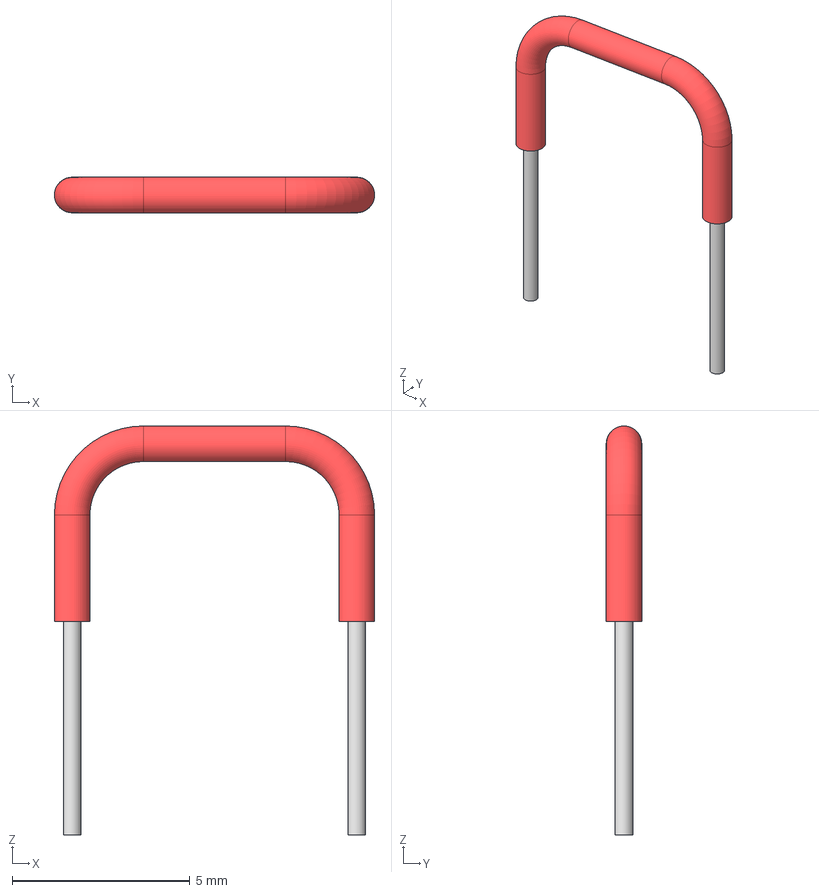
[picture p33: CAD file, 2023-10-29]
pcb/footprints/JumperWires/Jumper-Wire_8mm_Red.step
9.00 x 1 x 11.5 mm

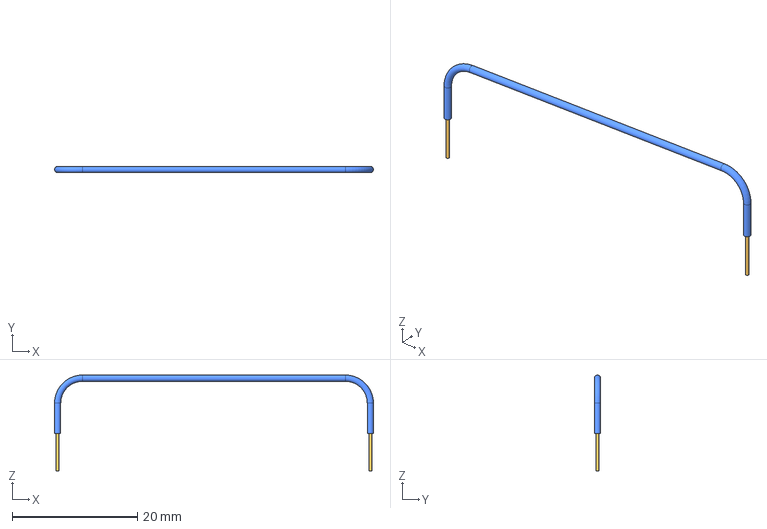
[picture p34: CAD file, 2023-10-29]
pcb/footprints/JumperWires/Jumper-Wire_50mm_Blue.step
51.0 x 1 x 15.3 mm

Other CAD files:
pcb/footprints/JumperWires/Jumper-Wire_8mm_Blue.step

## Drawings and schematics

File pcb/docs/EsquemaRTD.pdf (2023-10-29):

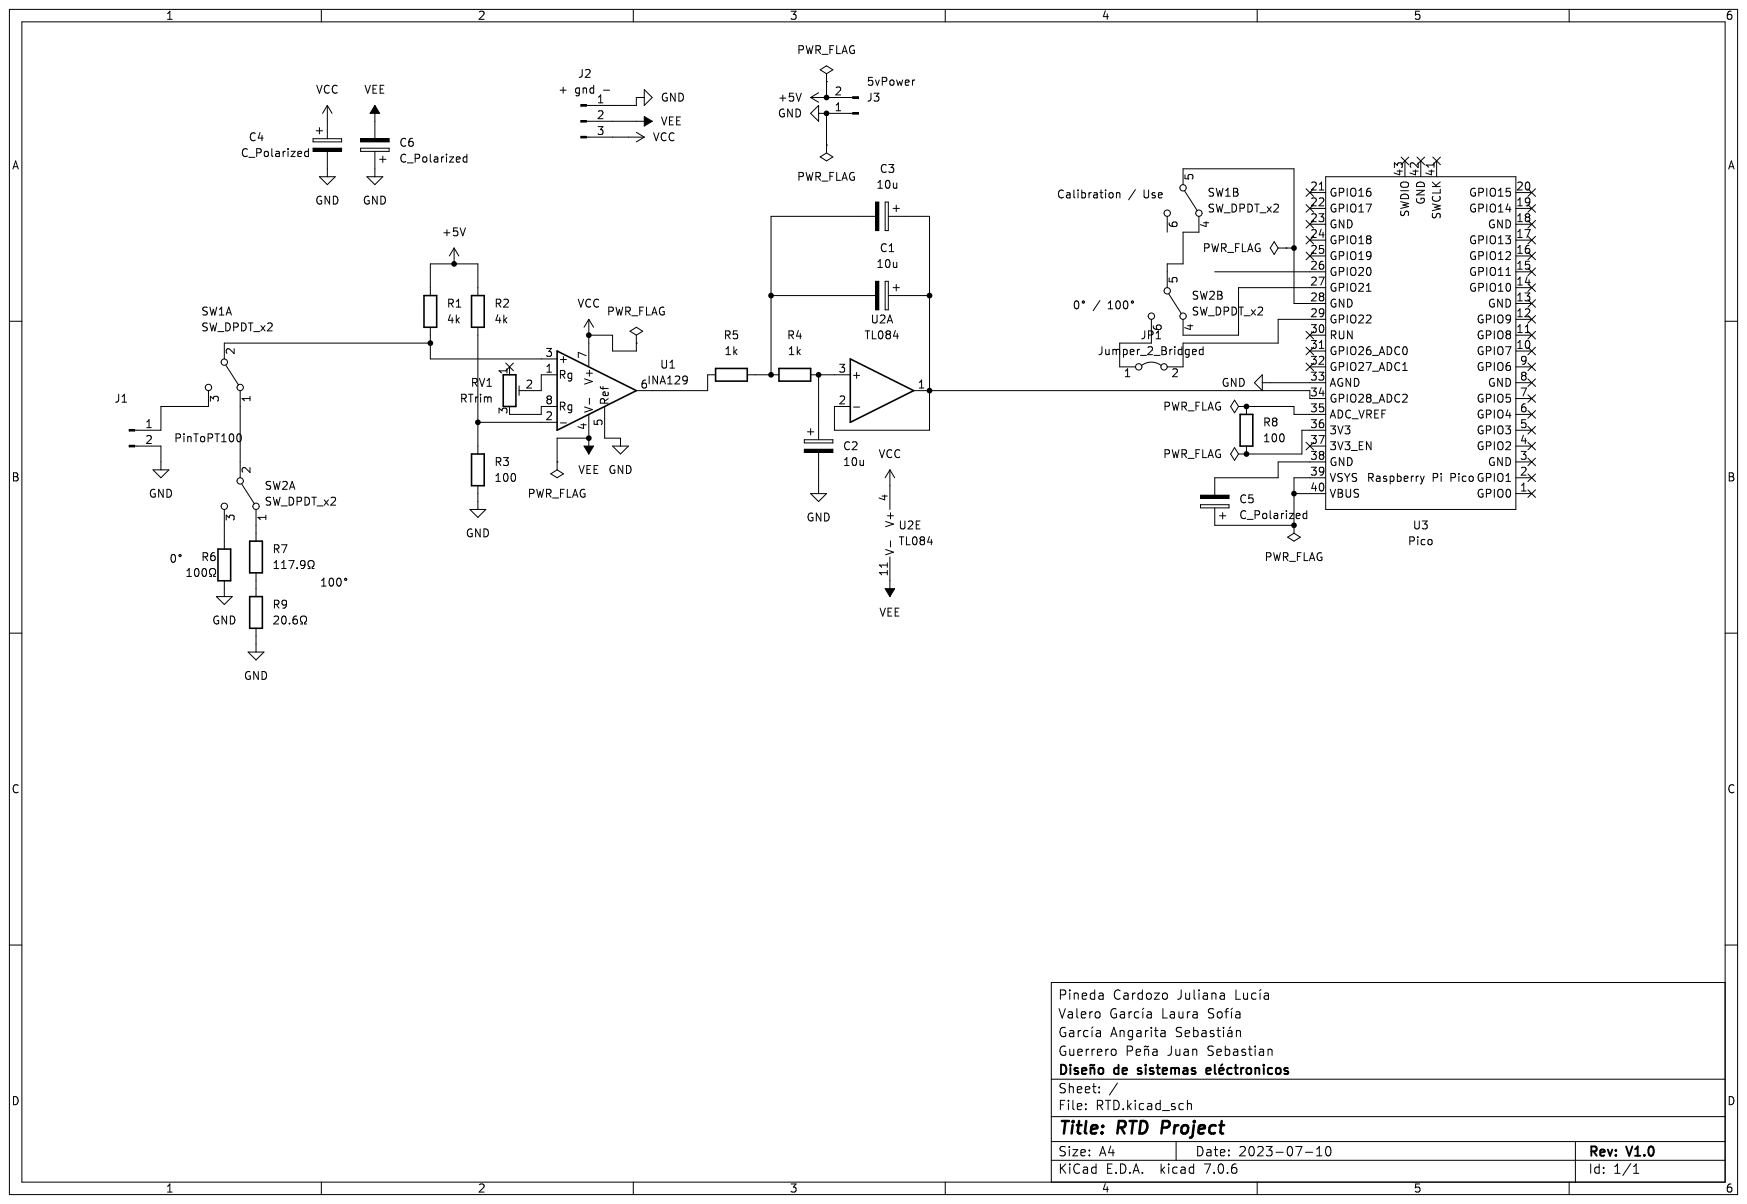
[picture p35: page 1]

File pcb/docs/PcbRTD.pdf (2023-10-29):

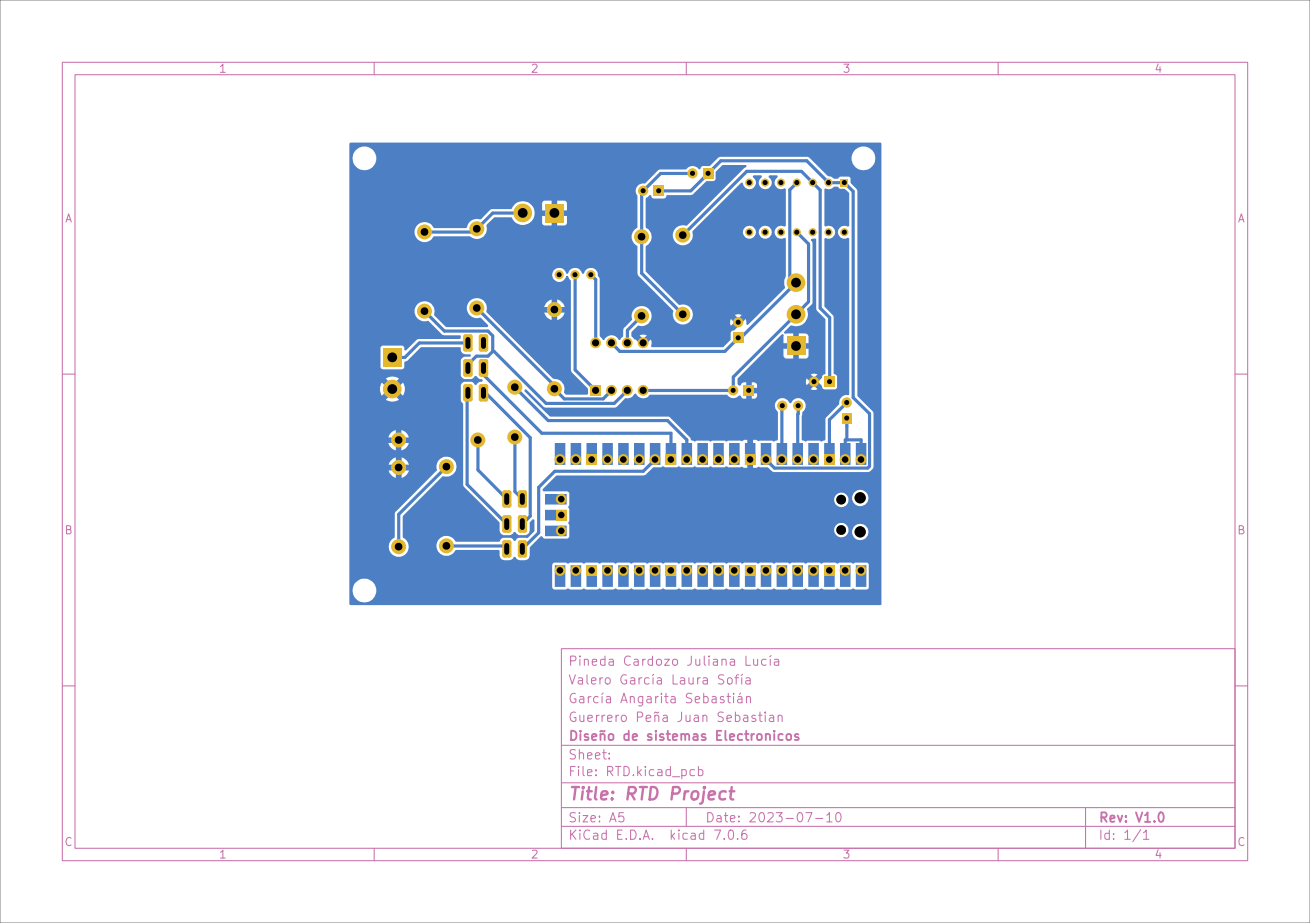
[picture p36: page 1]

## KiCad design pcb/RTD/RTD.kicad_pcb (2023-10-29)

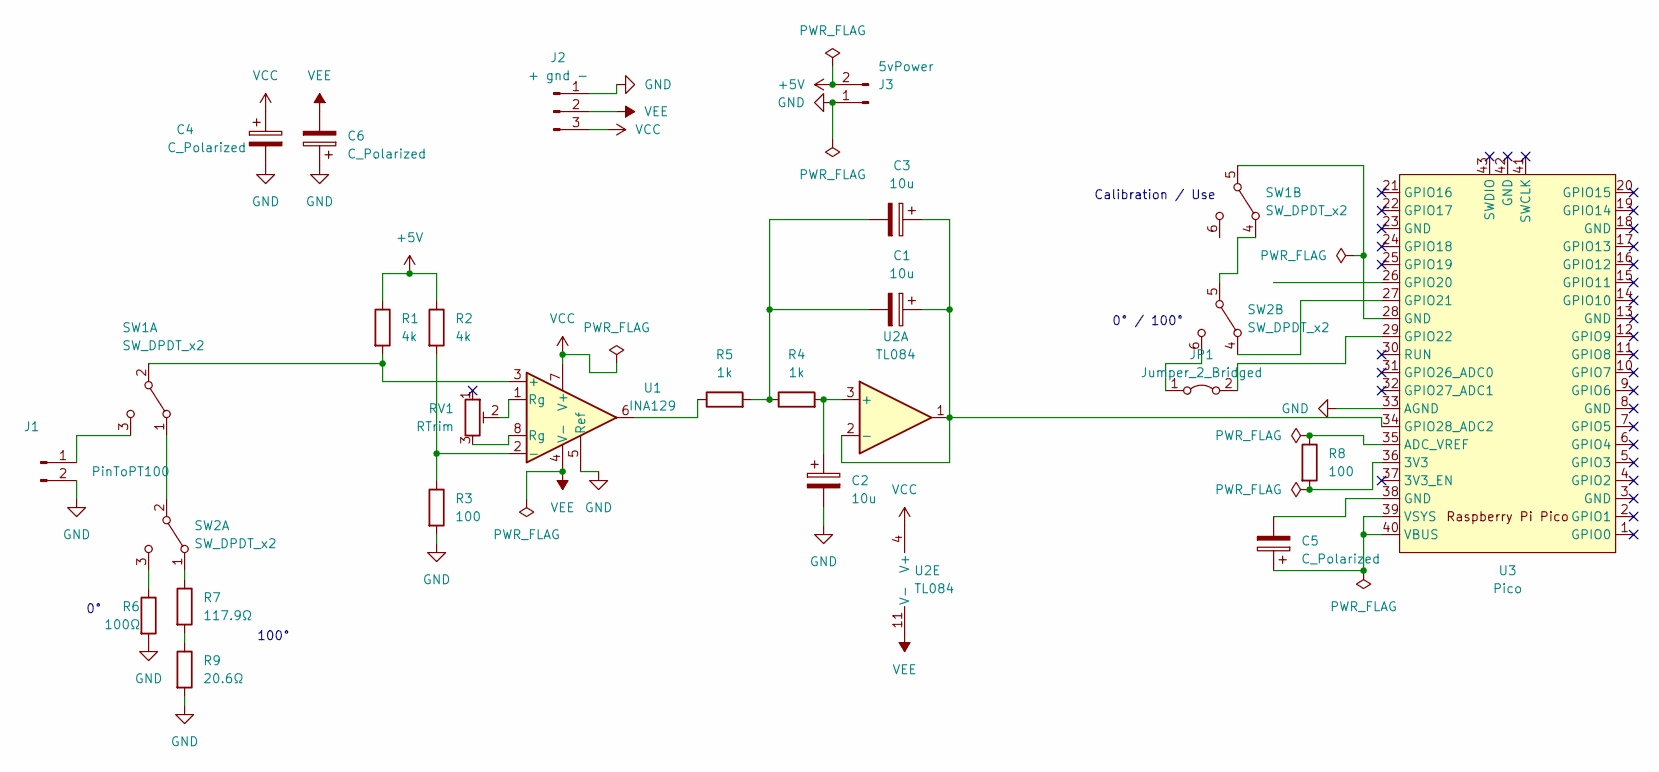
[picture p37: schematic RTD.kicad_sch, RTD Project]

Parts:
C1, C2, C3: 10u; CP_Radial_D5.0mm_P2.50mm
C4, C5, C6: C_Polarized; CP_Radial_D5.0mm_P2.50mm
J1: PinToPT100; TerminalBlock_bornier-2_P5.08mm
J2: + gnd -; TerminalBlock_bornier-3_P5.08mm
J3: 5vPower; TerminalBlock_bornier-2_P5.08mm
JP1: Jumper_2_Bridged; jumper-wire_8mm
R1, R2: 4k; R_Axial_DIN0411_L9.9mm_D3.6mm_P12.70mm_Horizontal
R3: 100; R_Axial_DIN0411_L9.9mm_D3.6mm_P12.70mm_Horizontal
R4, R5: 1k; R_Axial_DIN0411_L9.9mm_D3.6mm_P12.70mm_Horizontal
R6: 100Ω; R_Axial_DIN0411_L9.9mm_D3.6mm_P12.70mm_Horizontal
R7: 117.9Ω; R_Axial_DIN0411_L9.9mm_D3.6mm_P12.70mm_Horizontal
R8: 100; R_Axial_DIN0309_L9.0mm_D3.2mm_P2.54mm_Vertical
R9: 20.6Ω; R_Axial_DIN0411_L9.9mm_D3.6mm_P12.70mm_Horizontal
RV1: RTrim; Potentiometer_Bourns_3386C_Horizontal
SW1, SW2: SW_DPDT_x2; DIP-Switch-2P2T
U1: INA129; DIP254P762X508-8
U2: TL084; DIP794W45P254L1969H508Q14
U3: Pico; RPi_Pico_SMD_TH

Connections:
+5V: J3.2, R1.1, R2.1
GND: C2.2, C4.2, C6.1, J1.2, J2.1, J3.1, R3.2, R6.2, R9.2, U1.5 (Ref), U3.33 (AGND)
unnamed: C1.2, C3.2, R4.1, R5.2
unnamed: C5.2, U3.38 (GND)
unnamed: J1.1, SW1.3 (C)
unnamed: JP1.1 (A), SW2.6 (C)
unnamed: JP1.2 (B), U3.29 (GPIO22)
unnamed: R5.1, U1.6
unnamed: R7.2, R9.1
unnamed: RV1.2, U1.1 (Rg)
unnamed: RV1.3, U1.8 (Rg)
unnamed: SW1.1 (A), SW2.2 (B)
unnamed: R1.2, SW1.2 (B), U1.3 (+)
unnamed: SW1.4 (A), SW2.5 (B)
unnamed: SW1.5 (B), U3.28 (GND)
unnamed: R7.1, SW2.1 (A)
unnamed: R6.1, SW2.3 (C)
unnamed: SW2.4 (A), U3.27 (GPIO21)
unnamed: R2.2, R3.1, U1.2 (-)
unnamed: C2.1, R4.2, U2.3 (+)
unnamed: C1.1, C3.1, U2.1, U2.2 (-), U3.34 (GPIO28_ADC2)
unnamed: R8.2, U3.36 (3V3)
unnamed: R8.1, U3.35 (ADC_VREF)
unnamed: C5.1, U3.39 (VSYS), U3.40 (VBUS)
VCC: C4.1, J2.3, U1.7 (V+), U2.4 (V+)
VEE: C6.2, J2.2, U1.4 (V-), U2.11 (V-)

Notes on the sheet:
0° / 100°
100°
Calibration / Use

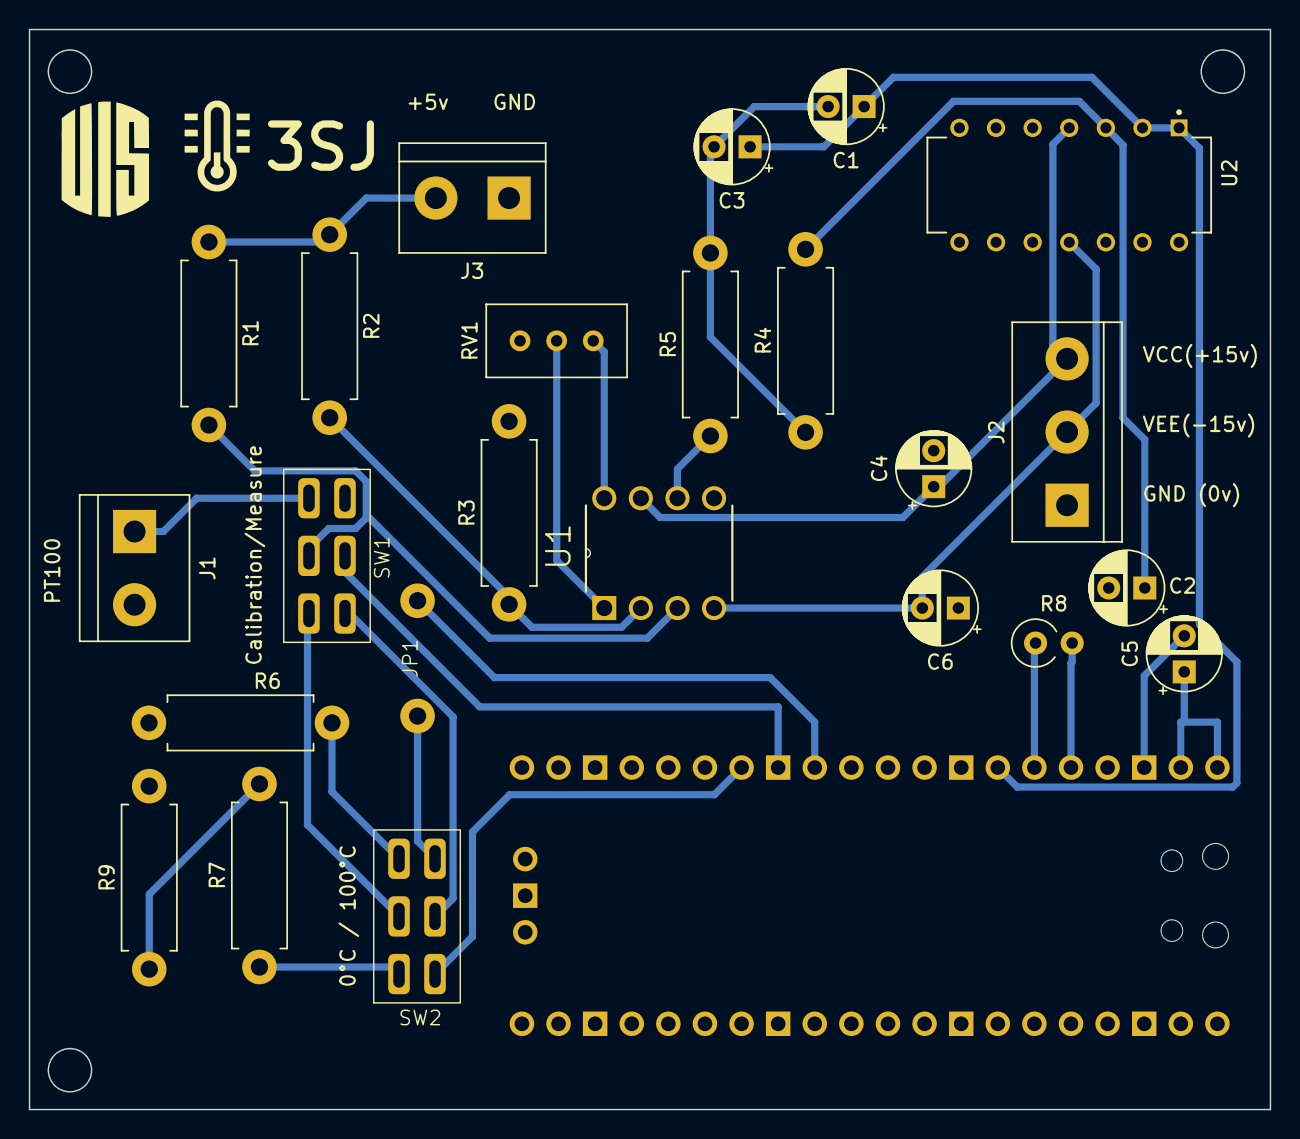
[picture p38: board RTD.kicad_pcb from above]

Board: 2 copper layers, 86.1 x 74.9 mm, 25 parts (1 on the bottom side), 26 nets.
